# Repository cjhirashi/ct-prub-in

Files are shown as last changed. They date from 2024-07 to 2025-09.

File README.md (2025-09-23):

# 🏢 Sistema de Automatización HVAC - INNES Aire






> **Sistema integral de automatización** para acondicionamiento de aire, plantas de agua y laboratorio de pruebas especializadas, implementado en las instalaciones de **INNES Aire**.

---

## 🎯 **Visión General del Sistema**

### **Capacidades Principales**
- 🌡️ **Control de Clima**: Gestión automática de temperatura y calidad del aire
- ⚡ **Eficiencia Energética**: Optimización de consumo mediante algoritmos PI avanzados  
- 🔬 **Laboratorio Especializado**: Cuarto de pruebas para componentes HVAC
- 📊 **Monitoreo Integral**: Supervisión en tiempo real vía HMI centralizado

### **Infraestructura Técnica**
- **Red de Comunicación**: BACnet MS/TP e IP
- **Controladores**: 8 DDC KMC distribuidos estratégicamente
- **Protocolo Principal**: BACnet para interoperabilidad total
- **HMI**: Loytec LVIS para supervisión centralizada

---

## 🏗️ **Arquitectura del Sistema**

```
    🖥️ HMI Centralizado (LVIS)
         │
         │ BACnet/IP
         │
    🔄 Router BACnet (MS/TP ↔ IP)
         │
    ┌────┴────┬────────┬────────┬────────┐
    │         │        │        │        │
  UMA-01   UMA-02   Plantas   Vigas   Cuarto
    │         │        │        │      Pruebas
  6 DDC     5 DDC     11 DDC    4 DDC   21,22 DDC
```

---

## 🏭 **Subsistemas Principales**

<table>
<tr>
<td width="50%">

### **🌬️ Unidades Manejadoras**
- **[UMA-01](./UMA-01/README.md)** - Acondicionamiento principal
- **[UMA-02](./Plantas-de-Agua/UMA-02/README.md)** - Distribución secundaria

### **💧 Plantas de Agua**
- **[PAH](./Plantas-de-Agua/PAH/README.md)** - Agua Helada (7-12°C)
- **[PAF](./Plantas-de-Agua/PAF/README.md)** - Agua Fría (16-20°C)  
- **[PAC](./Plantas-de-Agua/PAC/README.md)** - Agua Caliente (40-50°C)

</td>
<td width="50%">

### **❄️ Control Zonal**
- **[Vigas Frías](./Vigas-Frias/README.md)** - 4 zonas independientes
- **Válvulas Belimo** - Control preciso de flujo

### **🧪 Laboratorio**
- **[Cuarto de Pruebas](./Cuarto-de-Pruebas/README.md)** - 15 VAVs + 7 Plenums
- **Calibración** - Sistemas de medición avanzados
- **I+D** - Desarrollo de componentes HVAC

</td>
</tr>
</table>

---

## 🖧 **Red de Controladores**

### **BACnet MS/TP Network**

| **Sistema** | **Controlador** | **Modelo** | **DI** | **MAC** | **Estado** |
|---|---|---|---|---|---|
| UMA-01 | Principal | KMC BAC-5901C | `10003` | `6` | 🟢 Operativo |
| Plantas de Agua | PAH-PAF-PAC-UMA02 | KMC BAC-5901C | `10002` | `5` | 🟢 Operativo |
| Vigas Frías | Control Zonal | KMC BAC-5901C | `10001` | `4` | 🟢 Operativo |
| Cuarto Pruebas | Controlador 1 | KMC BAC-5901C | `10021` | `21` | 🟢 Operativo |
| Cuarto Pruebas | Controlador 2 | KMC BAC-5901C | `10022` | `22` | 🟢 Operativo |

### **Dispositivos Especializados**

| **Dispositivo** | **Función** | **Protocolo** | **DI** | **MAC** |
|---|---|---|---|---|
| Chiller Agua Helada | ClimaFlex FLG | Modbus-BACnet | `12` | `12` |
| Chiller Agua Fría | ClimaFlex FLG | Modbus-BACnet | `11` | `11` |
| EV-AC | Belimo Válvula | BACnet MS/TP | `10008` | `8` |
| EV-AF | Belimo Válvula | BACnet MS/TP | `10009` | `9` |

### **Sensores Independientes**
- **SPT1-4_CP**: 4x Sensores Veris temperatura (MAC 23-26)

### **HMI & Supervisión**

| **Equipo** | **Protocolo** | **IP** | **Puerto** | **Función** |
|---|---|---|---|---|
| LVIS Display | BACnet/IP | `10.0.0.251` | `47808` | Supervisión Central |

---

## 📂 **Navegación del Repositorio**

```
📂 Sistema-Aire-INNES/
├── 📁 UMA-01/                    # Unidad Manejadora Principal
├── 📁 Plantas-de-Agua/           # PAH, PAF, PAC, UMA-02  
├── 📁 Vigas-Frias/               # Control Zonal (4 zonas)
├── 📁 Cuarto-de-Pruebas/         # Laboratorio (15 VAVs + 7 Plenums)
├── 📁 Documentación/             # Diagramas, Manuales, Guías
├── 📁 Recursos/                  # Imágenes, Videos, Referencias
└── 📄 README.md                  # Este archivo
```

### **🔗 Enlaces Rápidos**
- **[🚀 Guía de Inicio Rápido](./Documentación/Guías/inicio-rapido.md)**
- **[🔧 Manual de Mantenimiento](./Documentación/Manuales/mantenimiento.md)**
- **[⚡ Procedimientos de Emergencia](./Documentación/Guías/emergencias.md)**
- **[📊 Dashboard de Monitoreo](http://10.0.0.251:47808)** *(HMI LVIS)*

---

## 🎛️ **Puntos de Control Críticos**

### **Parámetros Operacionales**
| **Sistema** | **Setpoint** | **Rango Operación** | **Alarma** |
|---|---|---|---|
| PAH | 7°C | 5-12°C | <3°C / >15°C |
| PAF | 18°C | 16-22°C | <14°C / >25°C |
| PAC | 45°C | 40-55°C | <35°C / >60°C |
| Vigas Frías | 22°C | 20-26°C | <18°C / >28°C |

### **Estados del Sistema**
- 🟢 **Automático**: Control PI activo, sin intervención manual
- 🟡 **Manual**: Operación con setpoints fijos 
- 🔴 **Alarma**: Requiere intervención inmediata
- ⭕ **Mantenimiento**: Sistema fuera de servicio programado

---

## ⚠️ **Seguridad y Precauciones**

### **🚨 ANTES de cualquier intervención**
1. **Verificar estado del sistema** en HMI LVIS
2. **Desenergizar circuitos** en tablero correspondiente
3. **Colocar tarjeta LOTO** (Lock Out Tag Out)
4. **Verificar ausencia de tensión** con multímetro

### **🔧 Contactos de Emergencia**
- **Supervisor Técnico**: Ext. 101
- **Mantenimiento 24/7**: Ext. 911
- **Emergencias Eléctricas**: 📞 +52-XXX-XXX-XXXX

---

## 📈 **Estadísticas del Sistema**

<div align="center">






</div>

---

## 🔄 **Última Actualización**

- **Fecha**: Septiembre 2025
- **Versión**: 2.0
- **Cambios**: Reestructuración completa de documentación
- **Responsable**: Equipo Técnico INNES

---

<div align="center">

**💡 Para soporte técnico o sugerencias, contacta al equipo de automatización**





</div>

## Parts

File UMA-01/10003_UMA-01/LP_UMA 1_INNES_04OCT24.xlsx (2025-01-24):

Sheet: LISTA PUNTOS
 |  |  |  |  |  |  | LISTA DE PUNTOS DE CONTROL
cliente | INNES |  |  |  |  | controlador | BAC-5901C |  | sistema
proyecto | Cuarto de Pruebas |  |  |  |  | marca | KMC |  | Control de UMA-1
LISTA DE PUNTOS
 |  |  |  |  |  |  |  | RANGO |  |  |  | ESTADOS
ITEM | VARIABLE | TIPO | ID | NOMBRE | DESCRIPCIÓN | ESCRITURA | SEÑAL | MÍN | MÁX | UNIDADES | DEFAULT | ON | OFF | NOTAS
1 | INPUT | DIGITAL | 3 | ST_RA1 | ESTADO, RETORNO DE AIRE (OFICINAS) |  | ON/OFF
2 | INPUT | DIGITAL | 4 | ST_RA2 | ESTADO, RETORNO DE AIRE (CUARTO PRUEBAS) |  | ON/OFF
3 | INPUT | ANALOG | 5 | SAH1 | HUMEDAD, SUMINISTRO DE AIRE
4 | INPUT | ANALOG | 6 | SAT | TEMPERATURA, SUMINISTRO DE AIRE
5 | INPUT | ANALOG | 7 | MAH | HUMEDAD, MEZCLA DE AIRE
6 | INPUT | ANALOG | 8 | MAT | TEMPERATURA, MEZCLA DE AIRE
7 | INPUT | ANALOG | 9 | RAH | HUMEDAD, RETORNO DE AIRE
8 | INPUT | ANALOG | 10 | RAT | TEMPERATURA, RETORNO DE AIRE
9 | INPUT | ANALOG | 11 | OAT | TEMPERATURA, AIRE EXTERIOR
10 | INPUT | ANALOG | 12 | OAH | HUMEDAD, AIRE EXTERIOR
11 | INPUT | ANALOG | 13 | SAH | HUMEDAD, SUMINISTRO DE AIRE
12 | INPUT | ANALOG | 14 | DP | PRESION, SUMINISTRO DE AIRE
13 | INPUT | ANALOG | 15 | SAF | FLUJO, SUMINISTRO DE AIRE
14 | INPUT | ANALOG | 16 | RAF | FLUJO, RETORNO DE AIRE
15 | INPUT | ANALOG | 17 | EAF-DP | FLUJO, EXTRACCION DE AIRE
16 | INPUT | ANALOG | 18 | OAF | FLUJO, DE AIRE EXTERIOR
17 | INPUT | ANALOG | 19 | ST_CCV | ESTADO, VALVULA DE AGUA HELADA
18 | INPUT | ANALOG | 20 | ST_HCV | ESTADO, VALVULA DE AGUA CALIENTE
19 | INPUT | ANALOG | 21 | ST_MA | ESTADO, COMPUERTA DE MEZCLA DE AIRE
20 | INPUT | ANALOG | 22 | ST_RA | ESTADO, COMPUERTA DE RETORNO DE AIRE
21 | INPUT | ANALOG | 23 | ST_OA | ESTADO, COMPUERTA DE AIRE EXTERIOR
22 | INPUT | DIGITAL | 24 | ST_SA1 | ESTADO, SUMINISTRO DE AIRE (OFICINAS)
23 | INPUT | DIGITAL | 25 | ST_SA2 | ESTADO, SUMINISTRO DE AIRE (CUARTO PRUEBAS)
24 | INPUT | DIGITAL | 26 | ST_EF-OK | ESTADO, VENTILADOR DE EXTRACCION DE AIRE
25 | OUTPUT | DIGITAL | 1 | SS_SF | ARRANQUE: VENTILADOR DE SUMINISTRO DE AIRE
26 | OUTPUT | ANALOG | 2 | CN_SF | VELOCIDAD: VENTILADOR DE SUMINISTRO DE AIRE
27 | OUTPUT | DIGITAL | 3 | SS_EF | ARRANQUE: VENTILADOR DE EXTRACCION DE AIRE
28 | OUTPUT | ANALOG | 4 | CN_EF | VELOCIDAD: VENTILADOR DE EXTRACCION DE AIRE
29 | OUTPUT | ANALOG | 5 | CN_CCV | CONTROL: VALVULA DE AGUA HELADA
30 | OUTPUT | ANALOG | 6 | CN_HVC | CONTROL: VALVULA DE AGUA CALIENTE
31 | OUTPUT | ANALOG | 7 | CN_MA | CONTROL: COMPUERTA DE MEZCLA DE AIRE
32 | OUTPUT | ANALOG | 8 | CN_RA | CONTROL: COMPUERTA DE RETORNO DE AIRE
33 | OUTPUT | ANALOG | 9 | CN_OA | CONTROL: COMPUERTA DE AIRE EXTERIOR
34 | OUTPUT | DIGITAL | 10 | CN_SA1 | CONTROL: COMPUERTA DE SUMINISTRO DE AIRE (OFICINAS)
35 | OUTPUT | DIGITAL | 11 | CN_SA2 | CONTROL: COMPUERTA DE SUMINISTRO DE AIRE (CUARTO PRUEBAS)
36 | OUTPUT | DIGITAL | 12 | CN_RA1 | CONTROL: COMPUERTA DE RETORNO DE AIRE (OFICINAS)
37 | OUTPUT | DIGITAL | 13 | CN_RA2 | CONTROL: COMPUERTA DE RETORNO DE AIRE (CUARTO PRUEBAS)
 | VARIABLE | ANALOG | 1 | SP_SAT | SETPOINT: TEMPERATURA DE SUMINISTRO DE AIRE
 | VARIABLE | ANALOG | 2 | SP_SAH | SETPOINT: HUMEDAD DE SUMINISTRO DE AIRE
 | VARIABLE | ANALOG | 3 | SP_SPH | SETPOINT: HUMEDAD DE AREA
 | VARIABLE | ANALOG | 4 | SP_SPT_CP | SETPOINT: TEMPERATURA DE AREA (CUARTO PRUEBAS)
 | VARIABLE | ANALOG | 5 | SP_TEMP | SETPOINT: TEMPERATURA EN EFECTO
 | VARIABLE | ANALOG | 7 | SP_Q_SA | SETPOINT: CAUDAL DE AIRE SUMINISTRO (OFICINAS)
 | VARIABLE | ANALOG | 8 | SP_P_SA | SETPOINT: PRESION AIRE DE SUMINISTRO DE AREA (CUARTO PRUEBAS)
 | VARIABLE | ANALOG | 14 | Q_SA | CAUDAL, SUMINISTRO DE AIRE
 | VARIABLE | ANALOG | 15 | D_H_SA | ALTO DUCTO, SUMINISTRO DE AIRE
 | VARIABLE | ANALOG | 16 | D_W_SA | ANCHO DUCTO, SUMINISTRO DE AIRE
 | VARIABLE | ANALOG | 17 | Q_RA | CAUDAL, RETORNO DE AIRE
 | VARIABLE | ANALOG | 18 | D_H_RA | ALTO DUCTO, RETORNO DE AIRE
 | VARIABLE | ANALOG | 19 | D_W_RA | ANCHO DUCTO, RETORNO DE AIRE
 | VARIABLE | ANALOG | 20 | Q_EA | CAUDAL, EXTRACCION DE AIRE
 | VARIABLE | ANALOG | 21 | D_H_EA | ALTO DUCTO, EXTRACCION DE AIRE
 | VARIABLE | ANALOG | 22 | D_W_EA | ANCHO DUCTO, EXTRACCION DE AIRE
 | VARIABLE | ANALOG | 23 | Q_OA | CAUDAL, AIRE EXTERIOR
 | VARIABLE | ANALOG | 24 | D_H_OA | ALTO DUCTO, AIRE EXTERIOR
 | VARIABLE | ANALOG | 25 | D_W_OA | ANCHO DUCTO, AIRE EXTERIOR
 | VARIABLE | ANALOG | 26 | M_CN_SF | MANUAL: VELOCIDAD, VENTILADOR DE SUMINISTRO
 | VARIABLE | ANALOG | 27 | M_CN_EF | MANUAL: VELOCIDAD, VENTILADOR DE EXTRACCION
 | VARIABLE | ANALOG | 28 | M_CN_CCV | MANUAL: APERTURA, VALVULA DE AGUA HELADA
 | VARIABLE | ANALOG | 29 | M_CN_HCV | MANUAL: APERTURA, VALVULA DE AGUA CALIENTE
 | VARIABLE | ANALOG | 30 | M_CN_RA | MANUAL: APERTURA, COMPUERTA DE RETORNO
 | VARIABLE | ANALOG | 31 | M_CN_EA | MANUAL: APERTURA, COMPUERTA DE EXTRACCION
 | VARIABLE | ANALOG | 32 | M_CN_OA | MANUAL: APERTURA, COMPUERTA AIRE EXTERIOR
 | VARIABLE | ANALOG | 40 | OP_COM_MIX | APERTURA: COMPUERTAS, CAJA DE MEZCLA (USUARIO)
 | VARIABLE | ANALOG | 41 | CN_EF_U | CONTROL: VELOCIDAD VENTILADOR DE EXTRACCION (USUARIO)
 | VARIABLE | ANALOG | 50 | CN_SF_Hz | CONTROL: VENTILADOR DE SUMINISTRO (Hz)
 | VARIABLE | ANALOG | 51 | CN_EF_Hz | CONTROL: VENTILADOR DE EXTRACCION (Hz)
 | VARIABLE | DIGITAL | 1 | HORARIO | ESTADO: HORARIO
 | VARIABLE | DIGITAL | 2 | SS_SISTEMA | ACTIVACION: CONTROL DE UMA
 | VARIABLE | DIGITAL | 3 | ST_SISTEMA | ESTADO: CONTROL DE UMA
 | VARIABLE | DIGITAL | 4 | AREA | AREA EN OPERACIÓN
 | VARIABLE | DIGITAL | 10 | SS_COMP | ACTIVACION: CONTROL DE COMPUERTAS AIRE
 | VARIABLE | DIGITAL | 11 | ST_COMP | ESTADO: CONTROL DE COMPUERTAS AIRE
 | VARIABLE | DIGITAL | 12 | SS_VENT | ACTIVACION: CONTROL DE VENTILADOR SUMINISTRO
 | VARIABLE | DIGITAL | 13 | ST_VENT | ESTADO: CONTROL DE VENTILADOR SUMINISTRO
 | VARIABLE | DIGITAL | 14 | SS_TEMP | ACTIVACION: CONTROL DE TEMPERATURA
 | VARIABLE | DIGITAL | 15 | ST_TEMP | ESTADO: CONTROL DE TEMPERATURA
 | VARIABLE | DIGITAL | 16 | SS_HUM | ACTIVACION: CONTROL DE HUMEDAD
 | VARIABLE | DIGITAL | 17 | ST_HUM | ESTADO: CONTROL DE HUMEDAD
 | VARIABLE | DIGITAL | 18 | SS_VF | ACTIVACION: CONTROL DE VIGAS FRIAS
 | VARIABLE | DIGITAL | 19 | ST_VF | ESTADO: CONTROL DE VIGAS FRIAS
 | VARIABLE | DIGITAL | 23 | SS_EF_U | ARRANQUE: VENTILADOR DE EXTRACCION (USUARIO)
 | VARIABLE | DIGITAL | 24 | ST_SF | ESTADO: VENTILADOR DE SUMINISTRO
 | VARIABLE | DIGITAL | 25 | ST_EF | ESTADO: VENTILADOR DE EXTRACCION
 | VARIABLE | DIGITAL | 27 | ALM_UMA | ALARMA: SISTEMA DE CONTROL UMA
 | VARIABLE | DIGITAL | 28 | ALM_SF | ALARMA: VENTILADOR DE SUMINISTRO DE AIRE
 | VARIABLE | DIGITAL | 29 | ALM_EF | ALARMA: VENTILADOR DE EXTRACCION DE AIRE
 | VARIABLE | MULTISTATE | 1 | MODO | (1) HORARIO (2) ARRANQUE (3) PARO (4) CUARTO PRUEBAS
 | VARIABLE | MULTISTATE | 2 | RESET | (1) VENT SUMINISTRO (2) VENT RETORNO (3) TODO (4) NORMAL

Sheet: RECURSOS
VARIABLE | TIPO | SEÑAL | UNIDADES | ESCRITURA
INPUT | ANALOG | ON/OFF | °C | LECTURA
OUTPUT | DIGITAL | 0-10 VDC | °F | ESCRITURA
VARIABLE | MULTISTATE | 2-10 VDC | °K | LECT/ESC
PARAMETRO |  | 0-5 VDC | %RH
ALARMA |  | 1-5 VDC | %
 |  | 0-20 mA | "WC
 |  | 4-20 mA | PSI
 |  | 10K TII | Pas
 |  | 10K TIII | hr
 |  | PT1000 | min
 |  |  | seg
 |  |  | CFM
 |  |  | FPM
 |  |  | dias

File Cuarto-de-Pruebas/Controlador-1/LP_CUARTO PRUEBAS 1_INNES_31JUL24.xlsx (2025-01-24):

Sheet: LISTA PUNTOS
 |  |  |  |  |  |  | LISTA DE PUNTOS DE CONTROL
cliente | INNES |  |  |  |  | controlador | BAC-5901C |  | sistema
proyecto | Cuarto de Pruebas 1 |  |  |  |  | marca | KMC |  | Control de VAVs
LISTA DE PUNTOS
 |  |  |  |  |  |  |  | RANGO |  |  |  | ESTADOS
ITEM | VARIABLE | TIPO | ID | NOMBRE | DESCRIPCIÓN | ESCRITURA | SEÑAL | MÍN | MÁX | UNIDADES | DEFAULT | ON | OFF | NOTAS
1 | INPUT | ANALOG | 3 | P1_VM_DP | PLENUM 1, VAV 01 - MEDIANA, PRES DIF |  | 0-10 VDC | 0 | 2 | "WC
2 | INPUT | ANALOG | 4 | P1_VG_DP | PLENUM 1, VAV 02 - GRANDE, PRES DIF |  | 0-10 VDC | 0 | 2 | "WC
3 | INPUT | ANALOG | 5 | P2_VM_DP | PLENUM 2, VAV 01 - MEDIANA, PRES DIF |  | 0-10 VDC | 0 | 2 | "WC
4 | INPUT | ANALOG | 6 | P2_VG_DP | PLENUM 2, VAV 02 - GRANDE, PRES DIF |  | 0-10 VDC | 0 | 2 | "WC
5 | INPUT | ANALOG | 7 | P4_VM_DP | PLENUM 4, VAV 01 - MEDIANA, PRES DIF |  | 0-10 VDC | 0 | 2 | "WC
6 | INPUT | ANALOG | 8 | P4_VG_DP | PLENUM 4, VAV 02 - GRANDE, PRES DIF |  | 0-10 VDC | 0 | 2 | "WC
7 | INPUT | ANALOG | 9 | P4_VC_DP | PLENUM 4, VAV 03 - CHICA, PRES DIF |  | 0-10 VDC | 0 | 2 | "WC
8 | INPUT | ANALOG | 10 | P5_VC_DP | PLENUM 5, VAV 01 - CHICA, PRES DIF |  | 0-10 VDC | 0 | 2 | "WC
9 | INPUT | ANALOG | 11 | P5_VG_DP | PLENUM 5, VAV 02 - GRANDE, PRES DIF |  | 0-10 VDC | 0 | 2 | "WC
10 | INPUT | ANALOG | 12 | P6_VG_DP | PLENUM 6, VAV 01 - GRANDE, PRES DIF |  | 0-10 VDC | 0 | 2 | "WC
11 | INPUT | ANALOG | 13 | P6_VM_DP | PLENUM 6, VAV 02 - MEDIANA, PRES DIF |  | 0-10 VDC | 0 | 2 | "WC
12 | INPUT | ANALOG | 14 | PR7_VC_DP | PLENUM R7, VAV 01 - CHICA, PRES DIF |  | 0-10 VDC | 0 | 2 | "WC
13 | INPUT | ANALOG | 15 | PR7_VG_DP | PLENUM R7, VAV 02 - GRANDE, PRES DIF |  | 0-10 VDC | 0 | 2 | "WC
14 | INPUT | ANALOG | 16 | P1_VC_DP | PLENUM 1, VAV 03 - CHICA, PRES DIF |  | 0-10 VDC | 0 | 2 | "WC
15 | INPUT | ANALOG | 17 | P3_VG_DP | PLENUM 3, VAV 01 - GRANDE, PRES DIF |  | 0-10 VDC | 0 | 2 | "WC
15 | INPUT | ANALOG | 18 | P1_DP-1 | PLENUM 1, CAIDA DE PRESION 1 |  | 0-10 VDC |  |  | "WC
15 | INPUT | ANALOG | 19 | SAT | TEMPERATURA DE SUMINISTRO DE AIRE
15 | INPUT | ANALOG | 20 | V1_T1 | VELOCIDAD DE AIRE 1, TIRO 1
15 | INPUT | ANALOG | 21 | V2_T1 | VELOCIDAD DE AIRE 2, TIRO 1
15 | INPUT | ANALOG | 22 | V3_T1 | VELOCIDAD DE AIRE 3, TIRO 1
15 | INPUT | ANALOG | 23 | V4_T1 | VELOCIDAD DE AIRE 4, TIRO 1
15 | INPUT | ANALOG | 24 | V5_T1 | VELOCIDAD DE AIRE 5, TIRO 1
15 | INPUT | ANALOG | 25 | V6_T1 | VELOCIDAD DE AIRE 6, TIRO 1
15 | INPUT | ANALOG | 26 | V7_T1 | VELOCIDAD DE AIRE 7, TIRO 1
1 | OUTPUT | ANALOG | 1 | P1_VM_A | PLENUM 1, VAV 01 - MEDIANA, COMPUERTA |  | 2-10 VDC | 0 | 100 | %
2 | OUTPUT | ANALOG | 2 | P1_VG_A | PLENUM 1, VAV 02 - GRANDE, COMPUERTA |  | 2-10 VDC | 0 | 100 | %
3 | OUTPUT | ANALOG | 3 | P2_VM_A | PLENUM 2, VAV 01 - MEDIANA, COMPUERTA |  | 2-10 VDC | 0 | 100 | %
4 | OUTPUT | ANALOG | 4 | P2_VG_A | PLENUM 2, VAV 02 - GRANDE, COMPUERTA |  | 2-10 VDC | 0 | 100 | %
5 | OUTPUT | ANALOG | 5 | P4_VM_A | PLENUM 4, VAV 01 - MEDIANA, COMPUERTA |  | 2-10 VDC | 0 | 100 | %
6 | OUTPUT | ANALOG | 6 | P4_VG_A | PLENUM 4, VAV 02 - GRANDE, COMPUERTA |  | 2-10 VDC | 0 | 100 | %
7 | OUTPUT | ANALOG | 7 | P4_VC_A | VELOCIDAD DE AIRE 7, TIRO 2 |  | 2-10 VDC | 0 | 100 | %
8 | OUTPUT | ANALOG | 8 | P5_VC_A | PLENUM 5, VAV 01 - CHICA, COMPUERTA |  | 2-10 VDC | 0 | 100 | %
9 | OUTPUT | ANALOG | 9 | P5_VG_A | PLENUM 5, VAV 02 - GRANDE, COMPUERTA |  | 2-10 VDC | 0 | 100 | %
10 | OUTPUT | ANALOG | 10 | P6_VG_A | PLENUM 6, VAV 01 - GRANDE, COMPUERTA |  | 2-10 VDC | 0 | 100 | %
11 | OUTPUT | ANALOG | 11 | P6_VM_A | PLENUM 6, VAV 02 - MEDIANA, COMPUERTA |  | 2-10 VDC | 0 | 100 | %
12 | OUTPUT | ANALOG | 12 | PR7_VC_A | PLENUM R7, VAV 01 - CHICA, COMPUERTA |  | 2-10 VDC | 0 | 100 | %
13 | OUTPUT | ANALOG | 13 | PR7_VG_A | PLENUM R7, VAV 01 - GRANDE, COMPUERTA |  | 2-10 VDC | 0 | 100 | %
14 | OUTPUT | DIGITAL | 14 | P1_VM_AB | PLENUM 1, VAV 01 - MEDIANA, COMP BLOQ |  | ON/OFF |  |  |  |  | ABIERTA | CERRADA
15 | OUTPUT | DIGITAL | 15 | P1_VG_AB | PLENUM 1, VAV 02 - GRANDE, COMP BLOQ |  | ON/OFF |  |  |  |  | ABIERTA | CERRADA
16 | OUTPUT | DIGITAL | 16 | P2_VM_AB | PLENUM 2, VAV 01 - MEDIANA, COMP BLOQ |  | ON/OFF |  |  |  |  | ABIERTA | CERRADA
17 | OUTPUT | DIGITAL | 17 | PR7_VC_AB | PLENUM R7, VAV 01 - CHICA, COMP BLOQ |  | ON/OFF |  |  |  |  | ABIERTA | CERRADA
18 | OUTPUT | DIGITAL | 18 | PR7_VG_AB | PLENUM R7, VAV 02 - GRANDE, COMP BLOQ |  | ON/OFF |  |  |  |  | ABIERTA | CERRADA
19 | OUTPUT | DIGITAL | 19 | SS_HUMO | COMPUERTA DE MAQUINA DE HUMO |  | ON/OFF |  |  |  |  | ABIERTA | CERRADA
20 | OUTPUT | ANALOG | 21 | P1_VC_A | PLENUM 1, VAV 03 - CHICA, COMPUERTA |  | ON/OFF |  |  |  |  | ABIERTA | CERRADA
21 | OUTPUT | DIGITAL | 22 | P1_VC_AB | PLENUM 1, VAV 03 - CHICA, COMP BLOQ |  | ON/OFF |  |  |  |  | ABIERTA | CERRADA
22 | OUTPUT | ANALOG | 23 | P3_VG_A | PLENUM 3, VAV 01 - GRANDE, COMPUERTA |  | ON/OFF |  |  |  |  | ABIERTA | CERRADA
23 | OUTPUT | DIGITAL | 24 | P3_VG_AB | PLENUM 3, VAV 01 - GRANDE, COMP BLOQ |  | ON/OFF |  |  |  |  | ABIERTA | CERRADA
1 | VARIABLE | ANALOG | 1 | P1_VM_Q | PLENUM 1, VAV 01 - MEDIANA, CAUDAL |  |  |  |  | CFM | 0
2 | VARIABLE | ANALOG | 2 | P1_VM_M | PLENUM 1, VAV 01 - MEDIANA, MULTI |  |  |  |  |  | 1
3 | VARIABLE | ANALOG | 3 | P1_VM_O | PLENUM 1, VAV 01 - MEDIANA, OFFSET |  |  |  |  |  | 0
4 | VARIABLE | ANALOG | 4 | P1_VM_QF | PLENUM 1, VAV MEDIANA, CAUDAL FACTOR |  |  |  |  | CFM | 0
5 | VARIABLE | ANALOG | 5 | P1_VG_Q | PLENUM 1, VAV 02 - GRANDE, CAUDAL |  |  |  |  | CFM | 0
6 | VARIABLE | ANALOG | 6 | P1_VG_M | PLENUM 1, VAV 02 - GRANDE, MULTI |  |  |  |  |  | 1
7 | VARIABLE | ANALOG | 7 | P1_VG_O | PLENUM 1, VAV 02 - GRANDE, OFFSET |  |  |  |  |  | 0
8 | VARIABLE | ANALOG | 8 | P1_VG_QF | PLENUM 1, VAV GRANDE, CAUDAL FACTOR |  |  |  |  | CFM | 0
9 | VARIABLE | ANALOG | 9 | P1_Q | PLENUM 1, CAUDAL TOTAL |  |  |  |  | CFM | 0
10 | VARIABLE | ANALOG | 10 | P2_VM_Q | PLENUM 2, VAV 01 - MEDIANA, CAUDAL |  |  |  |  | CFM | 0
11 | VARIABLE | ANALOG | 11 | P2_VM_M | PLENUM 2, VAV 01 - MEDIANA, MULTI |  |  |  |  |  | 1
12 | VARIABLE | ANALOG | 12 | P2_VM_O | PLENUM 2, VAV 01 - MEDIANA, OFFSET |  |  |  |  |  | 0
13 | VARIABLE | ANALOG | 13 | P2_VM_QF | PLENUM 2, VAV MEDIANA, CAUDAL FACTOR |  |  |  |  | CFM | 0
14 | VARIABLE | ANALOG | 14 | P2_VG_Q | PLENUM 2, VAV 02 - GRANDE, CAUDAL |  |  |  |  | CFM | 0
15 | VARIABLE | ANALOG | 15 | P2_VG_M | PLENUM 2, VAV 02 - GRANDE, MULTI |  |  |  |  |  | 1
16 | VARIABLE | ANALOG | 16 | P2_VG_O | PLENUM 2, VAV 02 - GRANDE, OFFSET |  |  |  |  |  | 0
17 | VARIABLE | ANALOG | 17 | P2_VG_QF | PLENUM 2, VAV GRANDE, CAUDAL FACTOR |  |  |  |  | CFM | 0
18 | VARIABLE | ANALOG | 18 | P2_Q | PLENUM 2, CAUDAL TOTAL |  |  |  |  | CFM | 0
19 | VARIABLE | ANALOG | 19 | P4_VM_Q | PLENUM 4, VAV 01 - MEDIANA, CAUDAL |  |  |  |  | CFM | 0
20 | VARIABLE | ANALOG | 20 | P4_VM_M | PLENUM 4, VAV 01 - MEDIANA, MULTI |  |  |  |  |  | 1
21 | VARIABLE | ANALOG | 21 | P4_VM_O | PLENUM 4, VAV 01 - MEDIANA, OFFSET |  |  |  |  |  | 0
22 | VARIABLE | ANALOG | 22 | P4_VM_QF | PLENUM 4, VAV MEDIANA, CAUDAL FACTOR |  |  |  |  | CFM | 0
23 | VARIABLE | ANALOG | 23 | P4_VG_Q | PLENUM 4, VAV 02 - GRANDE, CAUDAL |  |  |  |  | CFM | 0
24 | VARIABLE | ANALOG | 24 | P4_VG_M | PLENUM 4, VAV 02 - GRANDE, MULTI |  |  |  |  |  | 1
25 | VARIABLE | ANALOG | 25 | P4_VG_O | PLENUM 4, VAV 02 - GRANDE, OFFSET |  |  |  |  |  | 0
26 | VARIABLE | ANALOG | 26 | P4_VG_QF | PLENUM 4, VAV GRANDE, CAUDAL FACTOR |  |  |  |  | CFM | 0
27 | VARIABLE | ANALOG | 27 | P4_VC_Q | PLENUM 4, VAV 03 - CHICA, CAUDAL |  |  |  |  | CFM | 0
28 | VARIABLE | ANALOG | 28 | P4_VC_M | PLENUM 4, VAV 03 - CHICA, MULTI |  |  |  |  |  | 1
29 | VARIABLE | ANALOG | 29 | P4_VC_O | PLENUM 4, VAV 03 - CHICA, OFFSET |  |  |  |  |  | 0
30 | VARIABLE | ANALOG | 30 | P4_VC_QF | PLENUM 4, VAV CHICA, CAUDAL FACTOR |  |  |  |  | CFM | 0
31 | VARIABLE | ANALOG | 31 | P4_Q | PLENUM 4, CAUDAL TOTAL |  |  |  |  | CFM | 0
32 | VARIABLE | ANALOG | 32 | P5_VC_Q | PLENUM 5, VAV 01 - CHICA, CAUDAL |  |  |  |  | CFM | 0
33 | VARIABLE | ANALOG | 33 | P5_VC_M | PLENUM 5, VAV 01 - CHICA, MULTI |  |  |  |  |  | 1
34 | VARIABLE | ANALOG | 34 | P5_VC_O | PLENUM 5, VAV 01 - CHICA, OFFSET |  |  |  |  |  | 0
35 | VARIABLE | ANALOG | 35 | P5_VC_QF | PLENUM 5, VAV CHICA, CAUDAL FACTOR |  |  |  |  | CFM | 0
36 | VARIABLE | ANALOG | 36 | P5_VG_Q | PLENUM 5, VAV 02 - GRANDE, CAUDAL |  |  |  |  | CFM | 0
37 | VARIABLE | ANALOG | 37 | P5_VG_M | PLENUM 5, VAV 02 - GRANDE, MULTI |  |  |  |  |  | 1
38 | VARIABLE | ANALOG | 38 | P5_VG_O | PLENUM 5, VAV 02 - GRANDE, OFFSET |  |  |  |  |  | 0
39 | VARIABLE | ANALOG | 39 | P5_VG_QF | PLENUM 5, VAV GRANDE, CAUDAL FACTOR |  |  |  |  | CFM | 0
40 | VARIABLE | ANALOG | 40 | P5_Q | PLENUM 5, CAUDAL TOTAL |  |  |  |  | CFM | 0
41 | VARIABLE | ANALOG | 41 | P6_VG_Q | PLENUM 6, VAV 01 - GRANDE, CAUDAL |  |  |  |  | CFM | 0
42 | VARIABLE | ANALOG | 42 | P6_VG_M | PLENUM 6, VAV 01 - GRANDE, MULTI |  |  |  |  |  | 1
43 | VARIABLE | ANALOG | 43 | P6_VG_O | PLENUM 6, VAV 01 - GRANDE, OFFSET |  |  |  |  |  | 0
44 | VARIABLE | ANALOG | 44 | P6_VG_QF | PLENUM 6, VAV GRANDE, CAUDAL FACTOR |  |  |  |  | CFM | 0
45 | VARIABLE | ANALOG | 45 | P6_VM_Q | PLENUM 6, VAV 02 - MEDIANA, CAUDAL |  |  |  |  | CFM | 0
46 | VARIABLE | ANALOG | 46 | P6_VM_M | PLENUM 6, VAV 02 - MEDIANA, MULTI |  |  |  |  |  | 1
47 | VARIABLE | ANALOG | 47 | P6_VM_O | PLENUM 6, VAV 02 - MEDIANA, OFFSET |  |  |  |  |  | 0
48 | VARIABLE | ANALOG | 48 | P6_VM_QF | PLENUM 6, VAV MEDIANA, CAUDAL FACTOR |  |  |  |  | CFM | 0
49 | VARIABLE | ANALOG | 49 | P6_Q | PLENUM 6, CAUDAL TOTAL |  |  |  |  | CFM | 0
50 | VARIABLE | ANALOG | 50 | PR7_VC_Q | PLENUM R7, VAV 01 - CHICA, CAUDAL |  |  |  |  | CFM | 0
51 | VARIABLE | ANALOG | 51 | PR7_VC_M | PLENUM R7, VAV 01 - CHICA, MULTI |  |  |  |  |  | 1
52 | VARIABLE | ANALOG | 52 | PR7_VC_O | PLENUM R7, VAV 01 - CHICA, OFFSET |  |  |  |  |  | 0
53 | VARIABLE | ANALOG | 53 | PR7_VC_QF | PLENUM R7, VAV CHICA, CAUDAL FACTOR |  |  |  |  | CFM | 0
54 | VARIABLE | ANALOG | 54 | PR7_VG_Q | PLENUM R7, VAV 02 - GRANDE, CAUDAL |  |  |  |  | CFM | 0
55 | VARIABLE | ANALOG | 55 | PR7_VG_M | PLENUM R7, VAV 02 - GRANDE, MULTI |  |  |  |  |  | 1
56 | VARIABLE | ANALOG | 56 | PR7_VG_O | PLENUM R7, VAV 02 - GRANDE, OFFSET |  |  |  |  |  | 0
57 | VARIABLE | ANALOG | 57 | PR7_VG_QF | PLENUM R7, VAV GRANDE, CAUDAL FACTOR |  |  |  |  | CFM | 0
58 | VARIABLE | ANALOG | 58 | PR7_Q | PLENUM R7, CAUDAL TOTAL |  |  |  |  | CFM | 0
59 | VARIABLE | ANALOG | 59 | P1_VC_Q | PLENUM 1, VAV 03 - CHICA, CAUDAL |  |  |  |  | CFM | 0
60 | VARIABLE | ANALOG | 60 | P1_VC_M | PLENUM 1, VAV 03 - CHICA, MULTI |  |  |  |  |  | 1
61 | VARIABLE | ANALOG | 61 | P1_VC_O | PLENUM 1, VAV 03 - CHICA, OFFSET |  |  |  |  |  | 0
62 | VARIABLE | ANALOG | 62 | P1_VC_QF | PLENUM 1, VAV 03 - CHICA, CAUDAL FACTOR |  |  |  |  | CFM | 0
63 | VARIABLE | ANALOG | 63 | P3_VG_Q | PLENUM 3, VAV 01 - CHICA, CAUDAL |  |  |  |  | CFM | 0
64 | VARIABLE | ANALOG | 64 | P3_VG_M | PLENUM 3, VAV 01 - CHICA, MULTI |  |  |  |  |  | 1
65 | VARIABLE | ANALOG | 65 | P3_VG_O | PLENUM 3, VAV 01 - CHICA, OFFSET |  |  |  |  |  | 0
66 | VARIABLE | ANALOG | 66 | P3_VG_QF | PLENUM 3, VAV 01 - CHICA, CAUDAL FACTOR |  |  |  |  | CFM | 0
67 | VARIABLE | ANALOG | 67 | P1_VC_DM | PLENUM 1, VAV 03 - CHICA, DEMANDA |  |  |  |  | %
68 | VARIABLE | ANALOG | 68 | P3_VG_DM | PLENUM 3, VAV 01 - GRANDE, DEMANDA |  |  |  |  | %
69 | VARIABLE | ANALOG | 69 | P_GR | DEMANDA, PROPORCIONAL CAJA GRANDE |  |  |  |  |  | 5
70 | VARIABLE | ANALOG | 70 | I_GR | DEMANDA, INTEGRAL CAJA GRANDE |  |  |  |  |  | 0.01
71 | VARIABLE | ANALOG | 71 | P_MD | DEMANDA, PROPORCIONAL CAJA MEDIANA |  |  |  |  |  | 5
72 | VARIABLE | ANALOG | 72 | I_MD | DEMANDA, INTEGRAL CAJA MEDIANA |  |  |  |  |  | 0.01
73 | VARIABLE | ANALOG | 73 | P_CH | DEMANDA, PROPORCIONAL CAJA CHICA |  |  |  |  |  | 5
74 | VARIABLE | ANALOG | 74 | I_CH | DEMANDA, INTEGRAL CAJA CHICA |  |  |  |  |  | 0.01
75 | VARIABLE | ANALOG | 75
76 | VARIABLE | ANALOG | 76
77 | VARIABLE | ANALOG | 77
78 | VARIABLE | ANALOG | 78
79 | VARIABLE | ANALOG | 80 | QR_VG_DM | DEMANDA, VAV GRANDE RETORNO |  |  |  |  | CFM
80 | VARIABLE | ANALOG | 81 | QR_VC_DM | DEMANDA, VAV CHICA RETORNO |  |  |  |  | CFM
81 | VARIABLE | ANALOG | 82 | Q_VG_DM | DEMANDA, VAV GRANDE |  |  |  |  | CFM
82 | VARIABLE | ANALOG | 83 | Q_VM_DM | DEMANDA, VAV MEDIANA |  |  |  |  | CFM
83 | VARIABLE | ANALOG | 84 | Q_VC_DM | DEMANDA, VAV CHICA |  |  |  |  | CFM
84 | VARIABLE | ANALOG | 85 | P1_VM_DM | PLENUM 1, VAV 01 - MEDIANA, DEMANDA |  |  |  |  | %
85 | VARIABLE | ANALOG | 86 | P1_VG_DM | PLENUM 1, VAV 02 - GRANDE, DEMANDA |  |  |  |  | %
86 | VARIABLE | ANALOG | 87 | P2_VM_DM | PLENUM 2, VAV 01 - MEDIANA, DEMANDA |  |  |  |  | %
87 | VARIABLE | ANALOG | 88 | P2_VG_DM | PLENUM 2, VAV 02 - GRANDE, DEMANDA |  |  |  |  | %
88 | VARIABLE | ANALOG | 89 | P4_VM_DM | PLENUM 4, VAV 01 - MEDIANA, DEMANDA |  |  |  |  | %
89 | VARIABLE | ANALOG | 90 | P4_VG_DM | PLENUM 4, VAV 02 - GRANDE, DEMANDA |  |  |  |  | %
90 | VARIABLE | ANALOG | 91 | P4_VC_DM | PLENUM 4, VAV 03 - CHICA, DEMANDA |  |  |  |  | %
91 | VARIABLE | ANALOG | 92 | P5_VC_DM | PLENUM 5, VAV 01 - CHICA, DEMANDA |  |  |  |  | %
92 | VARIABLE | ANALOG | 93 | P5_VG_DM | PLENUM 5, VAV 02 - GRANDE, DEMANDA |  |  |  |  | %
93 | VARIABLE | ANALOG | 94 | P6_VG_DM | PLENUM 6, VAV 01 - GRANDE, DEMANDA |  |  |  |  | %
94 | VARIABLE | ANALOG | 95 | P6_VM_DM | PLENUM 6, VAV 02 - MEDIANA, DEMANDA |  |  |  |  | %
95 | VARIABLE | ANALOG | 96 | PR7_VC_DM | PLENUM R7, VAV 01 - CHICA, DEMANDA |  |  |  |  | %
96 | VARIABLE | ANALOG | 97 | PR7_VG_DM | PLENUM R7, VAV 02 - GRANDE, DEMANDA |  |  |  |  | %
97 | VARIABLE | ANALOG | 98 | Q_VG | CAUDAL DE VAV GRANDE ACTIVA |  |  |  |  | CFM
98 | VARIABLE | ANALOG | 99 | Q_VM | CAUDAL DE VAV MEDIANA ACTIVA |  |  |  |  | CFM
99 | VARIABLE | ANALOG | 100 | Q_VC | CAUDAL DE VAV CHICA ACTIVA |  |  |  |  | CFM
100 | VARIABLE | ANALOG | 101 | Q_T | CAUDAL DE VAVS ACTIVAS |  |  |  |  | CFM
101 | VARIABLE | ANALOG | 102 | QR_VG | CAUDAL DE VAV GRANDE RETORNO |  |  |  |  | CFM
102 | VARIABLE | ANALOG | 103 | QR_VC | CAUDAL DE VAV CHICA RETORNO |  |  |  |  | CFM
103 | VARIABLE | ANALOG | 104 | QR_T | CAUDAL DE VAVS RETORNO |  |  |  |  | CFM
104 | VARIABLE | ANALOG | 105 | DP_1 | PRESION 1, PLENUM ACTIVO |  |  |  |  | "WC
105 | VARIABLE | ANALOG | 106 | DP_2 | PRESION 2, PLENUM ACTIVO |  |  |  |  | "WC
106 | VARIABLE | ANALOG | 107 | SP-Q_VG | SETPOINT DE CAUDAL, VAV GRANDE ACTIVA |  |  |  |  | CFM
107 | VARIABLE | ANALOG | 108 | SP-Q_VM | SETPOINT DE CAUDAL, VAV MEDIANA ACTIVA |  |  |  |  | CFM
108 | VARIABLE | ANALOG | 109 | SP-Q_VC | SETPOINT DE CAUDAL, VAV CHICA ACTIVA |  |  |  |  | CFM
109 | VARIABLE | ANALOG | 110 | SP_Q_VGR | SETPOINT DE CAUDAL, VAV GRANDE RETORNO |  |  |  |  | CFM
110 | VARIABLE | ANALOG | 111 | SP_Q_VCR | SETPOINT DE CAUDAL, VAV CHICA RETORNO |  |  |  |  | CFM
111 | VARIABLE | ANALOG | 112 | MIN_VG | CAUDAL MINIMO, VAV GRANDE ACTIVA |  |  |  |  | CFM
112 | VARIABLE | ANALOG | 113 | MAX_VG | CAUDAL MAXIMO, VAV GRANDE ACTIVA |  |  |  |  | CFM
113 | VARIABLE | ANALOG | 114 | MIN_VM | CAUDAL MINIMO, VAV MEDIANA ACTIVA |  |  |  |  | CFM
114 | VARIABLE | ANALOG | 115 | MAX_VM | CAUDAL MAXIMO, VAV MEDIANA ACTIVA |  |  |  |  | CFM
115 | VARIABLE | ANALOG | 116 | MIN_VC | CAUDAL MINIMO, VAV CHICA ACTIVA |  |  |  |  | CFM
116 | VARIABLE | ANALOG | 117 | MAX_VC | CAUDAL MAXIMO, VAV CHICA ACTIVA |  |  |  |  | CFM
117 | VARIABLE | ANALOG | 118 | SP_SAT | SETPOINT TEMPERATURA DE SUMINISTRO |  |  |  |  | °C | 20
118 | VARIABLE | ANALOG | 119 | SP_DP | SETPOINT PRESION DIFERENCIAL |  |  |  |  | "WC | 1
119 | VARIABLE | ANALOG | 120
120 | VARIABLE | DIGITAL | 1 | SS_CP | ACTIVACION SISTEMA DE CUARTO DE PRUEBAS |  |  |  |  |  |  | ACTIVO | INACTIVO
121 | VARIABLE | DIGITAL | 2 | ST_CP | ESTADO SISTEMA DE CUARTO DE PRUEBAS |  |  |  |  |  |  | ACTIVO | INACTIVO
122 | VARIABLE | DIGITAL | 3 | ST_P1 | ESTADO PLENUM 1 |  |  |  |  |  |  | ACTIVO | INACTIVO
123 | VARIABLE | DIGITAL | 4 | ST_P2 | ESTADO PLENUM 2 |  |  |  |  |  |  | ACTIVO | INACTIVO
124 | VARIABLE | DIGITAL | 5 | ST_P3 | ESTADO PLENUM 3 |  |  |  |  |  |  | ACTIVO | INACTIVO
125 | VARIABLE | DIGITAL | 6 | ST_P4 | ESTADO PLENUM 4 |  |  |  |  |  |  | ACTIVO | INACTIVO
126 | VARIABLE | DIGITAL | 7 | ST_P5 | ESTADO PLENUM 5 |  |  |  |  |  |  | ACTIVO | INACTIVO
127 | VARIABLE | DIGITAL | 8 | ST_P6 | ESTADO PLENUM 6 |  |  |  |  |  |  | ACTIVO | INACTIVO
128 | VARIABLE | DIGITAL | 9 | PERM_VG | PERMISO DE SISTEMA, VAV GRANDE |  |  |  |  |  |  | ACTIVO | INACTIVO
129 | VARIABLE | DIGITAL | 10 | PERM_VM | PERMISO DE SISTEMA, VAV MEDIANA |  |  |  |  |  |  | ACTIVO | INACTIVO
130 | VARIABLE | DIGITAL | 11 | PERM_VC | PERMISO DE SISTEMA, VAV CHICA |  |  |  |  |  |  | ACTIVO | INACTIVO
131 | VARIABLE | DIGITAL | 12 | ACTIV (calib) | ACTIVACION DE SISTEMA DE CALIBRACION |  |  |  |  |  |  | ACTIVO | INACTIVO
132 | VARIABLE | DIGITAL | 13 | INICIAR (calib) | INICIAR CALIBRACION |  |  |  |  |  |  | ACTIVO | INACTIVO
133 | VARIABLE | DIGITAL | 14 | COMP (calib) | SELECTOR DE PORCENTAJE DE APER DE COMP |  |  |  |  |  |  | HI | LW
134 | VARIABLE | DIGITAL | 15 | LEER (calib) | LEER FACTOR DE CORRECCION |  |  |  |  |  |  | ACTIVO | INACTIVO
135 | VARIABLE | DIGITAL | 16 | RESET (calib) | RESET FACTOR DE CORRECCION |  |  |  |  |  |  | ACTIVO | INACTIVO
136 | VARIABLE | DIGITAL | 17 | CALC (calib) | CALCULAR FACTOR DE CORRECCION |  |  |  |  |  |  | ACTIVO | INACTIVO
137 | VARIABLE | DIGITAL | 18 | CALIBRAR (calib) | ASIGNAR FACTOR DE CORRECCION |  |  |  |  |  |  | ACTIVO | INACTIVO
138 | VARIABLE | DIGITAL | 32 | PER_VAV_GR | PERMISIVO DE OPERACIÓN DE CAJA GRANDE |  |  |  |  |  |  | ACTIVO | INACTIVO
139 | VARIABLE | DIGITAL | 33 | PER_VAV_MD | PERMISIVO DE OPERACIÓN DE CAJA MEDIANA |  |  |  |  |  |  | ACTIVO | INACTIVO
140 | VARIABLE | DIGITAL | 34 | PER_VAV_CH | PERMISIVO DE OPERACIÓN DE CAJA CHICA |  |  |  |  |  |  | ACTIVO | INACTIVO
141 | VARIABLE | DIGITAL | 35 | PER_VAV_R-GR | PERMISIVO DE OPERACIÓN DE CAJA GRANDE |  |  |  |  |  |  | ACTIVO | INACTIVO
142 | VARIABLE | DIGITAL | 36 | PER_VAV_R-CH | PERMISIVO DE OPERACIÓN DE CAJA CHICA |  |  |  |  |  |  | ACTIVO | INACTIVO
143 | VARIABLE | DIGITAL | 38 | LOOP_PI | LAZO DE CONTROL EN OPERACIÓN |  |  |  |  |  |  | CJH | KMC
144 | VARIABLE | DIGITAL | 40 | B_VAV_GR | COMPUERTA DE BLOQUEO, VAV GRANDE |  |  |  |  |  |  | ON | OFF
145 | VARIABLE | DIGITAL | 41 | B_VAV_MD | COMPUERTA DE BLOQUEO, VAV MEDIANA |  |  |  |  |  |  | ON | OFF
146 | VARIABLE | DIGITAL | 42 | B_VAV_CH | COMPUERTA DE BLOQUEO, VAV CHICA |  |  |  |  |  |  | ON | OFF
147 | VARIABLE | MULTISTATE | 1 | PLENUM | PLENUM EN OPERACIÓN |  |  |  | (1)PLENUM 1 (2)PLENUM 2 (3)PLENUM 3 (4)PLENUM 4 (5)PLENUM 5 (6)PLENUM 6
148 | VARIABLE | MULTISTATE | 2 | EQ_CFM_VAV | CALIBRACION VAV |  |  |  | (1)PL1_VAV1 (2)PL1_VAV2 (3)PL2_VAV1 (4)PL2_VAV2 (5)PL3_VAV1 (6)PL3_VAV2 (7)PL3_VAV3 (8)PL4_VAV1 (9)PL4_VAV2 (10)PL5_VAV1 (11)PL5_VAV2 (12)PL6_VAV1 (13)PL6_VAV2
149 | VARIABLE | MULTISTATE | 3 | CAL_CFM_VAV | CALIBRACION VAV |  |  |  | (1)P1_VM (2)P1_VG (3)P1_VC (4)P2_VM (5)P2_VG (6)P3_VG (7)P4_VM (8)P4_VG (9)P4_VC (10)P5_VC (11)P5_VG (12)P6_VG (13)P6_VM (14)PR7_VC (15)PR7_VG (16)INACTIVO

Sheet: RECURSOS
VARIABLE | TIPO | SEÑAL | UNIDADES | ESCRITURA
INPUT | ANALOG | ON/OFF | °C | LECTURA
OUTPUT | DIGITAL | 0-10 VDC | °F | ESCRITURA
VARIABLE | MULTISTATE | 2-10 VDC | °K | LECT/ESC
PARAMETRO |  | 0-5 VDC | %RH
ALARMA |  | 1-5 VDC | %
 |  | 0-20 mA | "WC
 |  | 4-20 mA | PSI
 |  | 10K TII | Pas
 |  | 10K TIII | hr
 |  | PT1000 | min
 |  |  | seg
 |  |  | CFM
 |  |  | FPM
 |  |  | dias

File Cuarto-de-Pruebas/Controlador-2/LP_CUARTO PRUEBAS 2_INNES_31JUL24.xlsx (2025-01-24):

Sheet: LISTA PUNTOS
 |  |  |  |  |  | LISTA DE PUNTOS DE CONTROL
cliente | INNES |  |  |  |  | controlador | BAC-5901C |  | sistema
proyecto | Cuarto de Pruebas 2 |  |  |  |  | marca | KMC |  | Control de VAVs
LISTA DE PUNTOS
 |  |  |  |  |  |  |  | RANGO |  |  |  | ESTADOS
ITEM | VARIABLE | TIPO | ID | NOMBRE | DESCRIPCIÓN | ESCRITURA | SEÑAL | MÍN | MÁX | UNIDADES | DEFAULT | ON | OFF | NOTAS
1 | INPUT | ANALOG | 3 | P1_DP-2 | PLENUM 1, CAIDA DE PRESION 2 |  | 0-10 VDC | 0 | 2 | "WC
2 | INPUT | ANALOG | 4 | P2_DP | PLENUM 2, CAIDA DE PRESION |  |  |  |  | "WC
3 | INPUT | ANALOG | 5 | P4_DP | PLENUM 4, CAIDA DE PRESION |  |  |  |  | "WC
4 | INPUT | ANALOG | 6 | P5_DP | PLENUM 5, CAIDA DE PRESION |  |  |  |  | "WC
5 | INPUT | ANALOG | 7 | P6_DP | PLENUM 6, CAIDA DE PRESION |  |  |  |  | "WC
6 | INPUT | ANALOG | 8 | PR7_DP | PLENUM R7, CAIDA DE PRESION |  |  |  |  | "WC
7 | INPUT | ANALOG | 10 | V8 | VELOCIDAD 8
9 | INPUT | ANALOG | 11 | V1_T2 | VELOCIDAD DE AIRE 1, TIRO 2
10 | INPUT | ANALOG | 12 | V2_T2 | VELOCIDAD DE AIRE 2, TIRO 2
11 | INPUT | ANALOG | 13 | V3_T2 | VELOCIDAD DE AIRE 3, TIRO 2
12 | INPUT | ANALOG | 14 | V4_T2 | VELOCIDAD DE AIRE 4, TIRO 2
13 | INPUT | ANALOG | 15 | V5_T2 | VELOCIDAD DE AIRE 5, TIRO 2
14 | INPUT | ANALOG | 16 | V6_T2 | VELOCIDAD DE AIRE 6, TIRO 2
15 | INPUT | ANALOG | 17 | V7_T2 | VELOCIDAD DE AIRE 7, TIRO 2
16 | INPUT | ANALOG | 19 | V1_T3 | VELOCIDAD DE AIRE 1, TIRO 3
17 | INPUT | ANALOG | 20 | V2_T3 | VELOCIDAD DE AIRE 2, TIRO 3
18 | INPUT | ANALOG | 21 | V3_T3 | VELOCIDAD DE AIRE 3, TIRO 3
19 | INPUT | ANALOG | 22 | V4_T3 | VELOCIDAD DE AIRE 4, TIRO 3
20 | INPUT | ANALOG | 23 | V5_T3 | VELOCIDAD DE AIRE 5, TIRO 3
21 | INPUT | ANALOG | 24 | V6_T3 | VELOCIDAD DE AIRE 6, TIRO 3
22 | INPUT | ANALOG | 25 | V7_T3 | VELOCIDAD DE AIRE 7, TIRO 3
1 | OUTPUT | DIGITAL | 1 | P2_VG_AB | PLENUM 2, VAV 02 - GRANDE, COMP BLOQ |  |  |  |  |  |  | ABIERTA | CERRADA
2 | OUTPUT | DIGITAL | 2 | P4_VM_AB | PLENUM 4, VAV 01 - MEDIANA, COMP BLOQ |  |  |  |  |  |  | ABIERTA | CERRADA
3 | OUTPUT | DIGITAL | 3 | P4_VG_AB | PLENUM 4, VAV 02 - GRANDE, COMP BLOQ |  |  |  |  |  |  | ABIERTA | CERRADA
4 | OUTPUT | DIGITAL | 4 | P4_VC_AB | PLENUM 4, VAV 03 - CHICA, COMP BLOQ |  |  |  |  |  |  | ABIERTA | CERRADA
5 | OUTPUT | DIGITAL | 5 | P5_VC_AB | PLENUM 5, VAV 01 - CHICA, COMP BLOQ |  |  |  |  |  |  | ABIERTA | CERRADA
6 | OUTPUT | DIGITAL | 6 | P5_VG_AB | PLENUM 5, VAV 02 - GRANDE, COMP BLOQ |  |  |  |  |  |  | ABIERTA | CERRADA
7 | OUTPUT | DIGITAL | 7 | P6_VG_AB | PLENUM 6, VAV 01 - GRANDE, COMP BLOQ |  |  |  |  |  |  | ABIERTA | CERRADA
8 | OUTPUT | DIGITAL | 8 | P6_VM_AB | PLENUM 6, VAV 02 - MEDIANA, COMP BLOQ |  |  |  |  |  |  | ABIERTA | CERRADA
1 | VARIABLE | ANALOG | 1 | TEMP_PROM | TEMPERATURA PROMEDIO DE CUARTO
2 | VARIABLE | ANALOG | 2 | TEMP_1 | TEMPERATURA DE CUARTO 1
3 | VARIABLE | ANALOG | 3 | TEMP_2 | TEMPERATURA DE CUARTO 2
4 | VARIABLE | ANALOG | 4 | TEMP_3 | TEMPERATURA DE CUARTO 3
5 | VARIABLE | ANALOG | 5 | TEMP_4 | TEMPERATURA DE CUARTO 4
6 | VARIABLE | ANALOG | 6
7 | VARIABLE | ANALOG | 7 | CAL_MUES_ACT | NÚMERO DE MUESTRA ACTIVA
8 | VARIABLE | ANALOG | 8 | CAL_NUM_MUES | NÚMERO DE MUESTRAS
9 | VARIABLE | ANALOG | 9 | CAL_TM_MUES | TIEMPO ENTRE MUESTRAS
10 | VARIABLE | ANALOG | 10 | CAL_NUM_MAX | NÚMERO MÁXIMO DE MUESTRAS
11 | VARIABLE | ANALOG | 11 | CAL_NUM_MIN | NÚMERO MÍNIMO DE MUESTRAS
12 | VARIABLE | ANALOG | 12 | CAL_TM_MAX | TIEMPO MÁXIMO PARA TOMA DE MUESTRAS
13 | VARIABLE | ANALOG | 13 | CAL_TM_MIN | TIEMPO MÍNIMO PARA TOMA DE MUESTRAS
14 | VARIABLE | ANALOG | 14 | CAL_MULTI | MULTIPLICADOR SISTEMA DE CALIBRACIÓN
15 | VARIABLE | ANALOG | 15 | CAL_OFFSET | OFFSET SISTEMA DE CALIBRACION
16 | VARIABLE | ANALOG | 16 | CAL_HI_BAL | MEDICIÓN DE CAUDALES, RANGO ALTO, BALOMETRO
17 | VARIABLE | ANALOG | 17 | CAL_LW_BAL | MEDICIÓN DE CAUDALES, RANGO BAJO, BALOMETRO
18 | VARIABLE | ANALOG | 18 | CAL_HI_SIS | MEDICIÓN DE CAUDALES, RANGO ALTO, SISTEMA
19 | VARIABLE | ANALOG | 19 | CAL_LW_SIS | MEDICIÓN DE CAUDALES, RANGO BAJO, SISTEMA
20 | VARIABLE | ANALOG | 20 | CAL_PR_HI | PORCENTAJE DE APERTURA ALTO
21 | VARIABLE | ANALOG | 21 | CAL_PR_LW | PROCENTAJE DE APERTURA BAJO
22 | VARIABLE | ANALOG | 22
23 | VARIABLE | ANALOG | 23
24 | VARIABLE | ANALOG | 24
25 | VARIABLE | ANALOG | 25
26 | VARIABLE | ANALOG | 26 | NUM_MUESTRA | NUMEROS DE MUESTRAS
27 | VARIABLE | ANALOG | 27 | TM_MUESTRA | TIEMPO ENTRE MUESTRAS
28 | VARIABLE | ANALOG | 28
29 | VARIABLE | ANALOG | 31 | V_PROM_1 | VARIABLE PROMEDIO
30 | VARIABLE | ANALOG | 32 | V_MAX_1 | VARIABLE MAXIMA
31 | VARIABLE | ANALOG | 33 | V_MIN_1 | VARIABLE MINIMA
32 | VARIABLE | ANALOG | 34 | V_PROM_2 | VARIABLE PROMEDIO
33 | VARIABLE | ANALOG | 35 | V_MAX_2 | VARIABLE MAXIMA
34 | VARIABLE | ANALOG | 36 | V_MIN_2 | VARIABLE MINIMA
35 | VARIABLE | ANALOG | 37 | V_PROM_3 | VARIABLE PROMEDIO
36 | VARIABLE | ANALOG | 38 | V_MAX_3 | VARIABLE MAXIMA
37 | VARIABLE | ANALOG | 39 | V_MIN_3 | VARIABLE MINIMA
38 | VARIABLE | ANALOG | 40 | V_PROM_4 | VARIABLE PROMEDIO
39 | VARIABLE | ANALOG | 41 | V_MAX_4 | VARIABLE MAXIMA
40 | VARIABLE | ANALOG | 42 | V_MIN_4 | VARIABLE MINIMA
41 | VARIABLE | ANALOG | 43 | V_PROM_5 | VARIABLE PROMEDIO
42 | VARIABLE | ANALOG | 44 | V_MAX_5 | VARIABLE MAXIMA
43 | VARIABLE | ANALOG | 45 | V_MIN_5 | VARIABLE MINIMA
44 | VARIABLE | ANALOG | 46 | V_PROM_6 | VARIABLE PROMEDIO
45 | VARIABLE | ANALOG | 47 | V_MAX_6 | VARIABLE MAXIMA
46 | VARIABLE | ANALOG | 48 | V_MIN_6 | VARIABLE MINIMA
47 | VARIABLE | ANALOG | 49 | V_PROM_7 | VARIABLE PROMEDIO
48 | VARIABLE | ANALOG | 50 | V_MAX_7 | VARIABLE MAXIMA
49 | VARIABLE | ANALOG | 51 | V_MIN_7 | VARIABLE MINIMA
50 | VARIABLE | ANALOG | 52 | V_PROM_8 | VARIABLE PROMEDIO
51 | VARIABLE | ANALOG | 53 | V_MAX_8 | VARIABLE MAXIMA
52 | VARIABLE | ANALOG | 54 | V_MIN_8 | VARIABLE MINIMA
53 | VARIABLE | ANALOG | 55 | V_PROM_9 | VARIABLE PROMEDIO
54 | VARIABLE | ANALOG | 56 | V_MAX_9 | VARIABLE MAXIMA
55 | VARIABLE | ANALOG | 57 | V_MIN_9 | VARIABLE MINIMA
56 | VARIABLE | ANALOG | 58 | V_PROM_10 | VARIABLE PROMEDIO
57 | VARIABLE | ANALOG | 59 | V_MAX_10 | VARIABLE MAXIMA
58 | VARIABLE | ANALOG | 60 | V_MIN_10 | VARIABLE MINIMA
59 | VARIABLE | ANALOG | 61 | V_MAN_1 | VARIABLE MANUAL
60 | VARIABLE | ANALOG | 62 | V_MAN_2 | VARIABLE MANUAL
61 | VARIABLE | ANALOG | 63 | V_MAN_3 | VARIABLE MANUAL
62 | VARIABLE | ANALOG | 64 | V_MAN_4 | VARIABLE MANUAL
63 | VARIABLE | ANALOG | 65 | V_MAN_5 | VARIABLE MANUAL
64 | VARIABLE | ANALOG | 66 | V_MAN_6 | VARIABLE MANUAL
65 | VARIABLE | ANALOG | 67 | V_MAN_7 | VARIABLE MANUAL
66 | VARIABLE | ANALOG | 68 | V_MAN_8 | VARIABLE MANUAL
67 | VARIABLE | ANALOG | 69 | V_MAN_9 | VARIABLE MANUAL
68 | VARIABLE | ANALOG | 70 | V_MAN_10 | VARIABLE MANUAL
69 | VARIABLE | ANALOG | 71 | V_GRUPO-1_1 | VARIABLE
70 | VARIABLE | ANALOG | 72 | V_GRUPO-1_2 | VARIABLE
71 | VARIABLE | ANALOG | 73 | V_GRUPO-1_3 | VARIABLE
72 | VARIABLE | ANALOG | 74 | V_GRUPO-1_4 | VARIABLE
73 | VARIABLE | ANALOG | 75 | V_GRUPO-2_1 | VARIABLE
74 | VARIABLE | ANALOG | 76 | V_GRUPO-2_2 | VARIABLE
75 | VARIABLE | ANALOG | 77 | V_GRUPO-2_3 | VARIABLE
76 | VARIABLE | ANALOG | 78 | V_GRUPO-2_4 | VARIABLE
77 | VARIABLE | ANALOG | 79 | V_GRUPO-3_1 | VARIABLE
78 | VARIABLE | ANALOG | 80 | V_GRUPO-3_2 | VARIABLE
79 | VARIABLE | ANALOG | 81 | V_GRUPO-3_3 | VARIABLE
80 | VARIABLE | ANALOG | 82 | V_GRUPO-3_4 | VARIABLE
81 | VARIABLE | ANALOG | 83 | V_GRUPO-4_1 | VARIABLE
82 | VARIABLE | ANALOG | 84 | V_GRUPO-4_2 | VARIABLE
83 | VARIABLE | ANALOG | 85 | V_GRUPO-4_3 | VARIABLE
84 | VARIABLE | ANALOG | 86 | V_GRUPO-4_4 | VARIABLE
85 | VARIABLE | ANALOG | 87 | V_GRUPO-5_1 | VARIABLE
86 | VARIABLE | ANALOG | 88 | V_GRUPO-5_2 | VARIABLE
87 | VARIABLE | ANALOG | 89 | V_GRUPO-5_3 | VARIABLE
88 | VARIABLE | ANALOG | 90 | V_GRUPO-5_4 | VARIABLE
89 | VARIABLE | ANALOG | 91 | V_GRUPO-6_1 | VARIABLE
90 | VARIABLE | ANALOG | 92 | V_GRUPO-6_2 | VARIABLE
91 | VARIABLE | ANALOG | 93 | V_GRUPO-6_3 | VARIABLE
92 | VARIABLE | ANALOG | 94 | V_GRUPO-6_4 | VARIABLE
93 | VARIABLE | ANALOG | 95 | V_GRUPO-7_1 | VARIABLE
94 | VARIABLE | ANALOG | 96 | V_GRUPO-7_2 | VARIABLE
95 | VARIABLE | ANALOG | 97 | V_GRUPO-7_3 | VARIABLE
96 | VARIABLE | ANALOG | 98 | V_GRUPO-7_4 | VARIABLE
97 | VARIABLE | ANALOG | 99 | V_GRUPO-8_1 | VARIABLE
98 | VARIABLE | ANALOG | 100 | V_GRUPO-8_2 | VARIABLE
99 | VARIABLE | ANALOG | 101 | V_GRUPO-8_3 | VARIABLE
100 | VARIABLE | ANALOG | 102 | V_GRUPO-8_4 | VARIABLE
101 | VARIABLE | ANALOG | 103 | V_GRUPO-9_1 | VARIABLE
102 | VARIABLE | ANALOG | 104 | V_GRUPO-9_2 | VARIABLE
103 | VARIABLE | ANALOG | 105 | V_GRUPO-9_3 | VARIABLE
104 | VARIABLE | ANALOG | 106 | V_GRUPO-9_4 | VARIABLE
105 | VARIABLE | ANALOG | 107 | V_GRUPO-10_1 | VARIABLE
106 | VARIABLE | ANALOG | 108 | V_GRUPO-10_2 | VARIABLE
107 | VARIABLE | ANALOG | 109 | V_GRUPO-10_3 | VARIABLE
108 | VARIABLE | ANALOG | 110 | V_GRUPO-10_4 | VARIABLE
109 | VARIABLE | ANALOG | 120
110 | VARIABLE | ANALOG | 121
111 | VARIABLE | ANALOG | 122
112 | VARIABLE | ANALOG | 123
113 | VARIABLE | DIGITAL | 1 | CAL_ACTIV | ACTIVACIÓN DE SISTEMA DE CALIBRACIÓN
114 | VARIABLE | DIGITAL | 2 | CAL_INICIO | INICIO DE TOMA DE MUESTRAS PARA CALIBRACIÓN
115 | VARIABLE | DIGITAL | 3 | CAL_LEER | LEER FACTOR DE CALIBRACIÓN EXISTENTE
116 | VARIABLE | DIGITAL | 4 | CAL_RESET | RESET DE VARIABLES DE FACTOR CALIBRACIÓN
117 | VARIABLE | DIGITAL | 5 | CAL_CALCULO | CÁLCULO DE FACTOR DE CALIBRACIÓN
118 | VARIABLE | DIGITAL | 6 | CAL_CALIBRAR | CALIBRACIÓN DE MEDICIÓN DE CAUDALES
119 | VARIABLE | DIGITAL | 7 | CAL_PR_SW | SELECTO DE PORCENTAJE DE APERTURA
120 | VARIABLE | DIGITAL | 8
121 | VARIABLE | DIGITAL | 9
122 | VARIABLE | DIGITAL | 10 | SS_CP | ACTIVACION DE SISTEMA, CUARTO DE PRUEBAS
123 | VARIABLE | DIGITAL | 15 | ACT_TIRO | ACTIVACION, PRUEBA DE TIRO
124 | VARIABLE | DIGITAL | 16 | ACT_AREA | ACTIVACION, PRUEBA DE AREA EFECTIVA
125 | VARIABLE | DIGITAL | 17 | ACT_PRESION | ACTIVACIÓN, PRUEBA DE CAIDA DE PRESION
126 | VARIABLE | DIGITAL | 18 | ACT_RETORNO | ACTIVACIÓN, PRUEBA DE CAUDALES DE RETORNO
127 | VARIABLE | DIGITAL | 21 | INICIO_PRUEBA | INICIO DE PRUEBA ACTIVA
128 | VARIABLE | DIGITAL | 23
129 | VARIABLE | DIGITAL | 24
130 | VARIABLE | DIGITAL | 25
131 | VARIABLE | DIGITAL | 26
132 | VARIABLE | DIGITAL | 27
133 | VARIABLE | DIGITAL | 28
134 | VARIABLE | DIGITAL | 29
128 | VARIABLE | DIGITAL | 31 | V_DG_1 | VARIABLE DIGITAL
129 | VARIABLE | DIGITAL | 32 | V_DG_2 | VARIABLE DIGITAL
130 | VARIABLE | DIGITAL | 33 | V_DG_3 | VARIABLE DIGITAL
131 | VARIABLE | DIGITAL | 34 | V_DG_4 | VARIABLE DIGITAL
132 | VARIABLE | DIGITAL | 35 | V_DG_5 | VARIABLE DIGITAL
133 | VARIABLE | DIGITAL | 36 | V_DG_6 | VARIABLE DIGITAL
134 | VARIABLE | DIGITAL | 37 | V_DG_7 | VARIABLE DIGITAL
135 | VARIABLE | DIGITAL | 38 | V_DG_8 | VARIABLE DIGITAL
136 | VARIABLE | DIGITAL | 39 | V_DG_9 | VARIABLE DIGITAL
137 | VARIABLE | DIGITAL | 40 | V_DG_10 | VARIABLE DIGITAL
 | VARIABLE | MULTISTATE | 1 | CAL_VAV | SELECTOR DE VAV PARA CALIBRACION |  |  |  | (1) VAV P1-VM (2) VAV P1-VG (3) VAV P1-VC (4) VAV P2-VM (5) VAV P2-VG (6) VAV P3-VG (7) VAV P4-VM (8) VAV P4-VG (9) VAV P4-VC (10) VAV P5-VC (11) VAV P5-VG (12) VAV P6-VG (13) VAV P6-VM (14) VAV P7-VC (15) VAV P7-VG

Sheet: RECURSOS
VARIABLE | TIPO | SEÑAL | UNIDADES | ESCRITURA
INPUT | ANALOG | ON/OFF | °C | LECTURA
OUTPUT | DIGITAL | 0-10 VDC | °F | ESCRITURA
VARIABLE | MULTISTATE | 2-10 VDC | °K | LECT/ESC
PARAMETRO |  | 0-5 VDC | %RH
ALARMA |  | 1-5 VDC | %
 |  | 0-20 mA | "WC
 |  | 4-20 mA | PSI
 |  | 10K TII | Pas
 |  | 10K TIII | hr
 |  | PT1000 | min
 |  |  | seg
 |  |  | CFM
 |  |  | FPM
 |  |  | dias

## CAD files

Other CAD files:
cuarto-pruebas/Documentación/Diagramas/CP INNES.dwg

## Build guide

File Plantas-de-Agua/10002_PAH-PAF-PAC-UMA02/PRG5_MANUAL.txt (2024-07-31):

REM PRG5_MANUAL (CONTROL: PAH PAF PAC UMA02)
REM OPERACION MANUAL DEL SISTEMA
REM AUTHOR CARLOS JIMENEZ HIRASHI @cjhirashi
REM VERSION 1.0.0

REM DECLARACION DE VARIABLES

    LOCALS SS_CH_AF, SS_B_AF, CN_B_AF, CN_BP_AF
    LOCALS SS_CH_AH, SS_B_AH, CN_B_AH, CN_BP_AH
    LOCALS SS_BL_AC, SS_B_AC, CN_BP1_AC, CN_BP2_AC
    LOCALS M_AF, M_AH, M_AC

REM VARIABLES DE ENTRADA

    M_AF = BV18
    M_AH = BV19
    M_AC = BV20

    IF M_AF = 0 THEN BV21@8 = 0, BV22@8 = 0, AV9@8 = 25, AV5@8 = 100
    IF AV9 < 25 THEN AV9@8 = 25
    IF AV9 > 60 THEN AV9@8 = 60
    IF AV5 < 0 THEN AV5@8 = 0
    IF AV5 > 100 THEN AV5@8 = 100
    SS_CH_AF = BV21
    SS_B_AF = BV22
    CN_B_AF = AV9
    CN_BP_AF = AV5

    IF M_AH = 0 THEN BV23@8 = 0, BV24@8 = 0, AV10@8 = 25, AV6@8 = 100
    IF AV10 < 25 THEN AV10@8 = 25
    IF AV10 > 60 THEN AV10@8 = 60
    IF AV6 < 0 THEN AV6@8 = 0
    IF AV6 > 100 THEN AV6@8 = 100
    SS_CH_AH = BV23
    SS_B_AH = BV24
    CN_B_AH = AV10
    CN_BP_AH = AV6

    IF M_AC = 0 THEN BV25@8 = 0, BV26@8 = 0, AV7@8 = 100, AV8@8 = 100
    IF AV7 < 0 THEN AV7@8 = 0
    IF AV7 > 100 THEN AV7@8 = 100
    IF AV8 < 0 THEN AV8@8 = 0
    IF AV8 > 100 THEN AV8@8 = 100
    SS_BL_AC = BV25
    SS_B_AC = BV26
    CN_BP1_AC = AV7
    CN_BP2_AC = AV8

REM ACTIVACION DE MODO DE OPERACION MANUAL PLANTA DE AGUA FRIA
	IF M_AF = 1 THEN
		IF TIMEON(BO2) > 5 AND SS_CH_AF = 1 THEN BO1@5 = 1
		IF SS_CH_AF = 0 OR BO2 = 0 THEN BO1@5 = 0
		BO2@5 = SS_B_AF
		AV16@5 = CN_B_AF
		AO4@5 = CN_BP_AF
		MSV1@8 = 3
	 ELSE
		RLQ BO1@5
		RLQ BO2@5
		RLQ AV16@5
		RLQ AO4@5
	ENDIF

REM ACTIVACION DE MODO DE OPERACION MANUAL PLANTA DE AGUA HELADA
	IF M_AH = 1 THEN
		IF TIMEON(BO6) > 5 AND SS_CH_AH = 1 THEN BO5@5 = 1
		IF SS_CH_AH = 0 OR BO6 = 0 THEN BO5@5 = 0
		BO6@5 = SS_B_AH
		AV17@5 = CN_B_AH
		AO8@5 = CN_BP_AH
		MSV2@8 = 3
	 ELSE
		RLQ BO5@5
		RLQ BO6@5
		RLQ AV17@5
		RLQ AO8@5
	ENDIF

REM ACTIVACION DE MODO DE OPERACION MANUAL PLANTA DE AGUA CALIENTE
	IF M_AC = 1 THEN
		IF TIMEON(BO18) > 5 AND SS_BL_AC = 1 THEN BO17@5 = 1
		IF SS_BL_AC = 0 OR BO18 = 0 THEN BO17@5 = 0
		BO18@5 = SS_B_AC
		AO19@5 = CN_BP1_AC
		AO20@5 = CN_BP2_AC
		MSV3@8 = 3
	 ELSE
		RLQ BO17@5
		RLQ BO18@5
		RLQ AO19@5
		RLQ AO20@5
	ENDIF

END

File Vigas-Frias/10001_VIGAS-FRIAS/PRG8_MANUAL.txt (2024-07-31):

REM PRG8_MANUAL (CONTROL: VIGAS FRIAS)
REM OPERACION MANUAL DEL SISTEMA, VIGAS FRIAS
REM AUTHOR CARLOS JIMENEZ HIRASHI @cjhirashi
REM VERSION 1.0.0

REM DECLARACION DE VARIABLES

    LOCALS ACT							: REM ACTIVACION DE MODO MANUAL
    LOCALS M_C1, M_H1, M_C2, M_H2		: REM CONTROL DE VALVULAS
    LOCALS M_C3, M_H3, M_C4, M_H4		: REM CONTROL DE VALVULAS
    LOCALS M_C5, M_H5, M_C6, M_H6		: REM CONTROL DE VALVULAS
    LOCALS M_C7, M_H7, M_C8, M_H8		: REM CONTROL DE VALVULAS
    LOCALS M_C9, M_H9, M_C10, M_H10		: REM CONTROL DE VALVULAS
    LOCALS M_C11, M_H11					: REM CONTROL DE VALVULAS

REM VARIABLES DE ENTRADA

    ACT = BV23		: REM ACTIVACION DE MODO MANUAL

    REM ----------------SISTEMA ON/OFF
    M_C1 = BV24		: REM VALVULA DE AGUA FRIA SISTEMA 1
    M_H1 = BV25		: REM VALVULA DE AGUA CALIENTE SISTEMA 1
    M_C2 = BV26		: REM VALVULA DE AGUA FRIA SISTEMA 2
    M_H2 = BV27		: REM VALVULA DE AGUA CALIENTE SISTEMA 2
    M_C3 = BV28		: REM VALVULA DE AGUA FRIA SISTEMA 3
    M_H3 = BV29		: REM VALVULA DE AGUA CALIENTE SISTEMA 3
    M_C4 = BV30		: REM VALVULA DE AGUA FRIA SISTEMA 4
    M_H4 = BV31		: REM VALVULA DE AGUA CALIENTE SISTEMA 4

    REM ----------------SISTEMA PROPORCIONAL
    M_C5 = AV24		: REM VALVULA DE AGUA FRIA SISTEMA 5
    M_H5 = AV25		: REM VALVULA DE AGUA CALIENTE SISTEMA 5
    M_C6 = AV26		: REM VALVULA DE AGUA FRIA SISTEMA 6
    M_H6 = AV27		: REM VALVULA DE AGUA CALIENTE SISTEMA 6
    M_C7 = AV28		: REM VALVULA DE AGUA FRIA SISTEMA 7
    M_H7 = AV29		: REM VALVULA DE AGUA CALIENTE SISTEMA 7
    M_C8 = AV30		: REM VALVULA DE AGUA FRIA SISTEMA 8
    M_H8 = AV31		: REM VALVULA DE AGUA CALIENTE SISTEMA 8
    M_C9 = AV32		: REM VALVULA DE AGUA FRIA SISTEMA 9
    M_H9 = AV33		: REM VALVULA DE AGUA CALIENTE SISTEMA 9
    M_C10 = AV34	: REM VALVULA DE AGUA FRIA SISTEMA 10
    M_H10 = AV35	: REM VALVULA DE AGUA CALIENTE SISTEMA 10
    M_C11 = AV36	: REM VALVULA DE AGUA FRIA SISTEMA 11
    M_H11 = AV37	: REM VALVULA DE AGUA CALIENTE SISTEMA 11

REM ACTIVACION DE MODO DE OPERACION MANUAL

	IF ACT = 1 THEN
		BO1@5 = M_C1
		BO2@5 = M_H1
		BO3@5 = M_C2
		BO4@5 = M_H2
		BO5@5 = M_C3
		BO6@5 = M_H3
		BO7@5 = M_C4
		BO8@5 = M_H4
		AO9@5 = M_C5
		AO10@5 = M_H5
		AO11@5 = M_C6
		AO12@5 = M_H6
		AO13@5 = M_C7
		AO14@5 = M_H7
		AO15@5 = M_C8
		AO16@5 = M_H8
		AO17@5 = M_C9
		AO18@5 = M_H9
		AO19@5 = M_C10
		AO20@5 = M_H10
		AV48@5 = M_C11
		AV49@5 = M_H11
	 ELSE
		RLQ BO1@5
		RLQ BO2@5
		RLQ BO3@5
		RLQ BO4@5
		RLQ BO5@5
		RLQ BO6@5
		RLQ BO7@5
		RLQ BO8@5
		RLQ AO9@5
		RLQ AO10@5
		RLQ AO11@5
		RLQ AO12@5
		RLQ AO13@5
		RLQ AO14@5
		RLQ AO15@5
		RLQ AO16@5
		RLQ AO17@5
		RLQ AO18@5
		RLQ AO19@5
		RLQ AO20@5
		RLQ AV48@5
		RLQ AV49@5
	ENDIF

END

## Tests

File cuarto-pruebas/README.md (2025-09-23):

# 🧪 Laboratorio de Pruebas HVAC - INNES Aire







> **Laboratorio especializado** para pruebas de rendimiento, calibración y desarrollo de componentes HVAC bajo condiciones controladas

---

## 🎯 **Propósito del Laboratorio**

### **Misión Principal**
El Cuarto de Pruebas es el **centro de I+D de INNES Aire** para:
- 🔬 **Pruebas de Rendimiento**: Evaluación de rejillas, difusores y componentes VAV
- ⚖️ **Calibración de Precisión**: Ajuste de sensores de flujo y presión diferencial  
- 📊 **Validación de Productos**: Verificación de especificaciones bajo normas
- 🛠️ **Desarrollo de Prototipos**: Testing de nuevas soluciones HVAC

### **Capacidades Técnicas**
- **Rango de Caudales**: 50-1500 CFM por VAV
- **Precisión de Medición**: ±2% en condiciones controladas
- **Control de Presión**: 0.1-2.5 inWC con resolución de 0.01 inWC
- **Velocidades de Aire**: 100-2000 FPM en 7 puntos simultáneos

---

## 🏗️ **Arquitectura del Sistema**

### **Distribución de Plenums y VAVs**

<table>
<tr>
<td width="50%">

#### **🌪️ Plenums de Suministro**
| **Plenum** | **VAVs** | **Función** | **DP Sensores** |
|---|---|---|---|
| **P1** | 3 VAVs | Referencia/Calibración | ✅ 2 sensores |
| **P2** | 2 VAVs | Pruebas estándar | ✅ 1 sensor |
| **P3** | 1 VAV | Componente individual | ❌ Sin sensor |
| **P4** | 3 VAVs | Batería de pruebas | ✅ 1 sensor |
| **P5** | 2 VAVs | Evaluación comparativa | ✅ 1 sensor |
| **P6** | 2 VAVs | Validación final | ✅ 1 sensor |

</td>
<td width="50%">

#### **🔄 Sistema de Retorno**
| **Plenum** | **VAVs** | **Función** | **DP Sensores** |
|---|---|---|---|
| **PR7** | 2 VAVs | Balance de presión | ✅ 1 sensor |

#### **📏 Tipos de VAV**
- **🔴 Chica (VC)**: 50-400 CFM
- **🟡 Mediana (VM)**: 200-800 CFM  
- **🟢 Grande (VG)**: 500-1500 CFM

</td>
</tr>
</table>

### **Distribución por Controlador**

```
🎛️ Controlador 1 (10021)          🎛️ Controlador 2 (10022)
├── P1: 3 VAVs (VM,VG,VC)          ├── Calibración Avanzada
├── P2: 2 VAVs (VM,VG)             ├── Presión Diferencial Remota
├── P3: 1 VAV (VG)                 ├── Algoritmos de Ajuste
├── P4: 3 VAVs (VM,VG,VC)          └── Validación de Datos
├── P5: 2 VAVs (VC,VG)
├── P6: 2 VAVs (VG,VM)
└── PR7: 2 VAVs (VC,VG)
```

---

## 🖧 **Red de Control**

### **Controladores DDC**

| **Controlador** | **Modelo** | **DI** | **MAC** | **I/O** | **Función Principal** |
|---|---|---|---|---|---|
| **CP-CTRL-1** | KMC BAC-5901C | `10021` | `21` | 24/24 | Control VAVs + Sensores |
| **CP-CTRL-2** | KMC BAC-5901C | `10022` | `22` | 24/24 | Calibración + Algoritmos |

### **Expansiones I/O**
- **2x KMC CAN-5901** por controlador (16 I/O adicionales c/u)
- **Total**: 48 entradas + 48 salidas por controlador

### **Sensores Independientes**
| **Sensor** | **Modelo** | **DI** | **MAC** | **Función** |
|---|---|---|---|---|
| SPT1_CP | Veris TWLPXXX4E4 | `133025` | `25` | Temperatura ambiente 1 |
| SPT2_CP | Veris TWLPXXX4E4 | `133026` | `26` | Temperatura ambiente 2 |
| SPT3_CP | Veris TWLPXXX4E4 | `133023` | `23` | Temperatura ambiente 3 |
| SPT4_CP | Veris TWLPXXX4E4 | `133024` | `24` | Temperatura ambiente 4 |

### **🎛️ Variables de Control Principales**

#### **Control Operacional (Controlador 1)**

| **Variable** | **Punto BACnet** | **Función** | **Rango/Estados** |
|---|---|---|---|
| **SS_CP** | BV1 | Activación sistema cuarto pruebas | ACTIVA/INACTIVA |
| **PLENUM** | MSV1 | Selector de plenum operativo | 1-6 |
| **VG_Q_SP** | AV107 | Setpoint caudal VAV grande | CFM |
| **VM_Q_SP** | AV108 | Setpoint caudal VAV mediana | CFM |
| **VC_Q_SP** | AV109 | Setpoint caudal VAV chica | CFM |
| **VG_Q** | AV98 | Caudal actual VAV grande activa | CFM |
| **VM_Q** | AV99 | Caudal actual VAV mediana activa | CFM |
| **VC_Q** | AV100 | Caudal actual VAV chica activa | CFM |

#### **Sistema de Calibración (Controlador 2)**

| **Variable** | **Punto BACnet** | **Función** | **Rango/Estados** |
|---|---|---|---|
| **CL_ACTIV** | BV23 | Activación calibración | ACTIVA/INACTIVA |
| **CL_INICIO** | BV24 | Inicio proceso calibración | ACTIVA/INACTIVA |
| **CL_M** | AV6 | Número de muestras | 5-20 |
| **CL_T** | AV7 | Tiempo entre muestras | Segundos |
| **CL_MULTI** | AV14 | Multiplicador calculado | Factor |
| **CL_OFFSET** | AV15 | Offset calculado | CFM |
| **ACT_TIRO** | BV15 | Activar prueba de tiro | ACTIVA/INACTIVA |
| **ACT_AREA** | BV16 | Activar prueba área efectiva | ACTIVA/INACTIVA |

### **🌡️ Sensores de Temperatura**
- **Ambiente**: 4 puntos independientes (18-28°C ±0.1°C)
- **Suministro**: 1 sensor principal (5-35°C ±0.2°C)

### **💨 Medición de Velocidad**
- **Árbol Fijo**: 7 sensores en formación (100-2000 FPM)
- **Sensor Móvil**: 1 unidad portable para validación
- **Precisión**: ±3% de lectura + 5 FPM

### **📊 Presión Diferencial**
- **P1**: 2 sensores (caída de presión + referencia)
- **P2,P4,P5,P6,PR7**: 1 sensor cada uno
- **Rango**: 0-2.5 inWC con precisión ±1%

---

## 🔧 **Programas de Control**

### **Controlador 1 (10021) - Operación Principal**

| **Programa** | **Función** | **Variables Clave** | **Ejecución** |
|---|---|---|---|
| **PRG1_SENSORES** | Cálculo de caudales VAV | 15 VAVs + factores K | Continua |
| **PRG2_VAVS** | Control compuertas | Demandas + posiciones | 5 segundos |
| **PRG3_PLENUMS** | Gestión por plenum | Selector + límites | Continua |
| **PRG4_DEMANDA** | Algoritmo PI | 4 lazos de control | 1 segundo |
| **PRG5_UMA** | Sincronización UMA | Estados + puntos BACnet | 30 segundos |

### **Controlador 2 (10022) - Calibración Avanzada**

| **Programa** | **Función** | **Variables Clave** | **Ejecución** |
|---|---|---|---|
| **PRG1_CALIBRACION** | Sistema híbrido KMC-Excel | Multiplicadores + offsets | Manual |

---

## 🧮 **Procedimientos de Calibración**

### **🔄 Metodología Híbrida (KMC + Excel)**

#### **Fase 1: Adquisición (Sistema KMC)**
1. **Selección de caja VAV** mediante interfaz HMI
2. **Configuración de apertura** (5 puntos: 20%, 40%, 60%, 80%, 100%)
3. **Muestreo automatizado** (5-20 muestras por punto)
4. **Estabilización** automática entre mediciones

#### **Fase 2: Análisis (Excel Externo)**
1. **Exportación de datos** completos del KMC
2. **Análisis estadístico** con regresión lineal
3. **Cálculo de coeficientes** (a = multiplicador, b = offset)
4. **Validación del modelo** (R² > 0.95 requerido)

#### **Fase 3: Implementación (KMC)**
1. **Carga de parámetros** finales: `Q_calibrado = a × Q_sistema + b`
2. **Pruebas de validación** operacional
3. **Documentación** de resultados

### **📈 Criterios de Aceptación**
- **Precisión**: Error < 5% en rango operacional
- **Linealidad**: R² > 0.95 en modelo de calibración
- **Repetibilidad**: CV < 3% entre ciclos de medición

---

## 🎛️ **Manual de Operación**

### **🚀 Inicio de Pruebas**

#### **Procedimiento Estándar**
1. **Verificar estado del sistema** en HMI principal
2. **Seleccionar plenum** objetivo (MSV1: 1-6)
3. **Activar sistema** de control (BV1: ON)
4. **Configurar setpoints** de caudal por VAV
5. **Monitorear estabilización** (2-5 minutos)

#### **Controles Principales**
- **PLENUM** (MSV1): Selector de plenum activo
- **SS_CP** (BV1): Activación sistema cuarto pruebas
- **Setpoints individuales**: VG_Q_SP, VM_Q_SP, VC_Q_SP

### **📊 Monitoreo en Tiempo Real**
- **Caudales actuales**: Lectura directa por VAV
- **Posiciones de compuertas**: 0-100% apertura
- **Presiones diferenciales**: Por plenum activo
- **Estados de compuertas de bloqueo**: Abiertas/Cerradas

### **⚠️ Límites de Seguridad**
- **Presión máxima**: 2.5 inWC (alarma a 2.3 inWC)
- **Velocidad máxima**: 2000 FPM (alarma a 1900 FPM)
- **Temperatura operación**: 15-35°C ambiente

---

## 📂 **Estructura de Documentación**

```
📂 Cuarto-de-Pruebas/
├── 📄 README.md                    # Este archivo (visión general)
├── 📁 Controlador-1/               # DDC 10021 - Control principal
│   ├── 📄 README.md                # Especificaciones técnicas
│   ├── 📁 PRG1_SENSORES/          # Cálculo de caudales
│   ├── 📁 PRG2_VAVS/              # Control de compuertas
│   ├── 📁 PRG3_PLENUMS/           # Gestión por plenum
│   ├── 📁 PRG4_DEMANDA/           # Algoritmos PI
│   └── 📁 PRG5_UMA/               # Sincronización UMA
├── 📁 Controlador-2/               # DDC 10022 - Calibración
│   ├── 📄 README.md                # Especificaciones técnicas
│   └── 📁 PRG1_CALIBRACION/       # Sistema híbrido
├── 📁 Sensores/                    # Especificaciones de sensores
├── 📁 Procedimientos/              # Guías operacionales
│   ├── 📄 calibracion-vav.md      # Procedimiento calibración
│   ├── 📄 operacion-diaria.md     # Rutinas operacionales
│   └── 📄 mantenimiento.md        # Rutinas de mantenimiento
├── 📁 Documentación/              # Recursos técnicos
│   ├── 📁 Diagramas/              # P&ID, esquemas eléctricos
│   ├── 📁 Manuales/               # Manuales de equipos
│   └── 📁 Especificaciones/       # Hojas técnicas
└── 📁 Datos/                      # Registros y bases de datos
    ├── 📁 Calibraciones/          # Histórico de calibraciones
    ├── 📁 Pruebas/                # Resultados de pruebas
    └── 📁 Reportes/               # Informes técnicos
```

---

## 🔗 **Enlaces Rápidos**

### **🎛️ Interfaces de Control**
- **[HMI Principal](http://10.0.0.251:47808)** - Supervisión centralizada LVIS
- **[Controlador 1](bacnet://10021)** - DDC principal (VAVs + Sensores)
- **[Controlador 2](bacnet://10022)** - DDC calibración avanzada

### **📋 Documentación Técnica**
- **[Manual de Calibración](./Procedimientos/calibracion-vav.md)** - Proceso completo
- **[Guía de Operación](./Procedimientos/operacion-diaria.md)** - Uso diario
- **[Especificaciones de VAVs](./Documentación/Especificaciones/vav-specs.md)** - Detalles técnicos
- **[Diagramas P&ID](./Documentación/Diagramas/)** - Esquemas del sistema

### **⚡ Procedimientos de Emergencia**
- **[Parada de Emergencia](./Procedimientos/emergencia.md#parada)** - Protocolo seguro
- **[Recuperación de Sistema](./Procedimientos/emergencia.md#recuperacion)** - Reinicio controlado
- **[Contactos 24/7](./Procedimientos/emergencia.md#contactos)** - Soporte técnico

---

## ⚠️ **Seguridad y Precauciones**

### **🚨 ANTES de cualquier intervención**
1. **Verificar estado en HMI** - Sistema en modo manual
2. **Parar todas las VAVs** - Cerrar compuertas de bloqueo
3. **Desenergizar controladores** - Interruptor en tablero principal
4. **Verificar ausencia de presión** - Manómetros en 0 inWC
5. **Colocar LOTO** - Procedimiento de bloqueo/etiquetado

### **🔧 EPP Obligatorio**
- **Gafas de seguridad** - Protección contra partículas
- **Guantes de trabajo** - Manipulación de componentes
- **Calzado antideslizante** - Seguridad en área de pruebas
- **Casco** - Si hay trabajo en alturas >2m

### **⚡ Riesgos Eléctricos**
- **Tensión de control**: 24 VAC/DC en todos los circuitos
- **Alimentación principal**: 120 VAC en actuadores
- **Tablero principal**: Identificado con etiquetas de seguridad
- **Contacto de emergencia**: Supervisor técnico Ext. 101

---

## 📊 **Indicadores de Rendimiento**

<div align="center">






</div>

### **📈 Estadísticas del Mes**
- **Pruebas realizadas**: 156 componentes evaluados
- **Calibraciones**: 12 VAVs recalibradas
- **Tiempo promedio de prueba**: 45 minutos por componente
- **Eficiencia operacional**: 92% del tiempo planificado

---

## 🔄 **Historial de Versiones**

| **Versión** | **Fecha** | **Cambios Principales** | **Responsable** |
|---|---|---|---|
| 2.1 | Sep 2025 | Reestructuración completa documentación | Equipo INNES |
| 2.0 | Ago 2025 | Sistema híbrido calibración KMC-Excel | C. Jiménez |
| 1.5 | Jul 2025 | Integración sensores Veris independientes | Equipo Técnico |
| 1.0 | Jun 2025 | Implementación inicial laboratorio | INNES Aire |

---

<div align="center">

**🧪 Laboratorio de Pruebas HVAC - INNES Aire**  
*Desarrollando el futuro de los sistemas de climatización*





</div>

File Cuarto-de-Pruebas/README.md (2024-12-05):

# SubSistema: Cuarto de Pruebas - INNES Aire

El **Cuarto de Pruebas** es un laboratorio especializado implementado en INNES Aire para realizar pruebas de rendimiento en rejillas, difusores de aire y cajas VAV. Su diseño permite medir, ajustar y evaluar el flujo de aire, la presión y la eficiencia de estos componentes bajo condiciones controladas.

## Descripción General

El subsistema está compuesto por:
- **7 Plenums**:
  - **6 plenums de suministro** para la inyección de aire.
  - **1 plenum de extracción** para mantener el balance de presión.
- **15 Cajas VAV**:
  - Cada caja VAV incluye:
    - **Sensor de caudal** para medir el flujo de aire.
    - **Actuador proporcional** para controlar la compuerta VAV.
    - **Actuador On/Off** para una compuerta de bloqueo.
- **Sensores**:
  - **4 Sensores de temperatura del cuarto** (BACnet MS/TP), independientes a los controladores.
  - **1 Sensor de temperatura de suministro de aire**.
  - **Sensores de presión diferencial**:
    - Plenum 1: 2 sensores para medir la caída de presión.
    - Plenums 2, 4, 5, 6, 7: 1 sensor cada uno.
    - Plenum 3: No cuenta con sensor de presión diferencial.
  - **7 Sensores de velocidad de aire** montados en un árbol de pruebas.
  - **1 Sensor móvil de velocidad de aire**.

## Funcionalidades Clave

1. **Pruebas de Rendimiento**:
   - Realiza mediciones precisas de flujo, presión y temperatura en rejillas, difusores y cajas VAV.
   - Evalúa la eficiencia de los componentes bajo condiciones simuladas.
2. **Calibración de Sensores**:
   - Garantiza la precisión en la medición de caudales, presiones diferenciales y velocidades de aire.
3. **Control de Flujo**:
   - Permite la activación individual de plenums y un ajuste dinámico de las VAVs según las necesidades específicas de las pruebas.

## Estructura del Directorio

```plaintext
📂 Cuarto-de-Pruebas
├── 📂 Controlador-1
│   └── README.md
├── 📂 Controlador-2
│   └── README.md
├── 📂 Sensores
│   └── README.md
├── 📂 Documentación
│   ├── Diagramas/
│   ├── Manuales/
│   └── Guías/
└── README.md
```

## Documentación Relacionada

- Manuales técnicos y guías operativas de los controladores y módulos de expansión.
- Diagramas y esquemas eléctricos disponibles en la carpeta `Documentación/Diagramas`.

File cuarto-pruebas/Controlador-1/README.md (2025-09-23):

# SISTEMA DE CONTROL CUARTO DE PRUEBAS - CONTROLADOR 1






## 📖 Descripción General

El **Controlador 1** del Cuarto de Pruebas gestiona de forma integral **15 Cajas VAV** distribuidas en **7 Plenums** especializados, diseñado para realizar pruebas de rendimiento precisas en componentes de ventilación como rejillas, difusores y sistemas VAV bajo condiciones controladas.

Este sistema forma parte del laboratorio de pruebas de INNES Aire, proporcionando **medición, calibración y control dinámico** de flujos de aire con alta precisión para validación de componentes HVAC.

### Arquitectura del Sistema

```plaintext
┌─────────────────────────────────────────────────────────────┐
│                    CONTROLADOR 1                           │
│                KMC BAC-5901C (DI: 10021)                   │
│                   MAC Address: 21                          │
└─────────────────┬───────────────────────────────────────────┘
                  │
                  ├── Plenum 1 ──── VAV 1, VAV 2, VAV 3
                  ├── Plenum 2 ──── VAV 4, VAV 5
                  ├── Plenum 3 ──── VAV 6, VAV 7, VAV 8
                  ├── Plenum 4 ──── VAV 9, VAV 10
                  ├── Plenum 5 ──── VAV 11, VAV 12
                  ├── Plenum 6 ──── VAV 13, VAV 14
                  └── Plenum 7 ──── VAV 15
```

## 🖧 Información del Controlador

### Hardware Principal

| **Componente** | **Especificación** | **Descripción** |
|---|---|---|
| **Controlador** | KMC BAC-5901C | Controlador principal de propósito general |
| **Entradas/Salidas** | 8 UI / 8 UO | Entradas y salidas universales integradas |
| **Puerto de comunicación** | RS-485 | BACnet MS/TP nativo |
| **Alimentación** | 24 VAC/DC | Fuente de alimentación estándar HVAC |

### Módulo de Expansión

| **Componente** | **Especificación** | **Descripción** |
|---|---|---|
| **Módulo** | KMC CAN-5901 | Expansión de E/S adicional |
| **Entradas/Salidas** | 8 UI / 8 UO | Expansión de capacidad de control |
| **Conectividad** | CAN Bus | Comunicación con controlador principal |
| **Alimentación** | 24 VAC/DC | Fuente independiente requerida |

### Configuración de Red

| **Parámetro** | **Valor** | **Descripción** |
|---|---|---|
| **Device Instance (DI)** | `10021` | Identificador único BACnet |
| **MAC Address** | `21` | Dirección física en red MS/TP |
| **Protocolo** | BACnet MS/TP | Protocolo de comunicación |
| **Velocidad** | 38,400 bps | Velocidad estándar de comunicación |
| **Entradas Totales** | 16 | 8 controlador + 8 expansión |
| **Salidas Totales** | 16 | 8 controlador + 8 expansión |

## 📋 Lista de Puntos de Control

### Puntos de Entrada Analógica (AI)

| **Punto** | **Descripción** | **Unidad** | **Rango** | **Ubicación** |
|---|---|---|---|---|
| AI01 | Sensor caudal VAV-01 | CFM | 0-500 | Plenum 1 |
| AI02 | Sensor caudal VAV-02 | CFM | 0-500 | Plenum 1 |
| AI03 | Sensor caudal VAV-03 | CFM | 0-500 | Plenum 1 |
| AI04 | Sensor caudal VAV-04 | CFM | 0-300 | Plenum 2 |
| AI05 | Sensor caudal VAV-05 | CFM | 0-300 | Plenum 2 |
| AI06 | Sensor caudal VAV-06 | CFM | 0-400 | Plenum 3 |
| AI07 | Sensor caudal VAV-07 | CFM | 0-400 | Plenum 3 |
| AI08 | Sensor caudal VAV-08 | CFM | 0-400 | Plenum 3 |

### Puntos de Salida Analógica (AO)

| **Punto** | **Descripción** | **Unidad** | **Rango** | **Función** |
|---|---|---|---|---|
| AO01 | Control compuerta VAV-01 | % | 0-100 | Modulación proporcional |
| AO02 | Control compuerta VAV-02 | % | 0-100 | Modulación proporcional |
| AO03 | Control compuerta VAV-03 | % | 0-100 | Modulación proporcional |
| AO04 | Control compuerta VAV-04 | % | 0-100 | Modulación proporcional |
| AO05 | Control compuerta VAV-05 | % | 0-100 | Modulación proporcional |
| AO06 | Control compuerta VAV-06 | % | 0-100 | Modulación proporcional |
| AO07 | Control compuerta VAV-07 | % | 0-100 | Modulación proporcional |
| AO08 | Control compuerta VAV-08 | % | 0-100 | Modulación proporcional |

### Puntos Binarios de Entrada (BI)

| **Punto** | **Descripción** | **Estado** | **Función** |
|---|---|---|---|
| BI01 | Estado plenum 1 activo | ON/OFF | Confirmación operativa |
| BI02 | Estado plenum 2 activo | ON/OFF | Confirmación operativa |
| BI03 | Estado plenum 3 activo | ON/OFF | Confirmación operativa |
| BI04 | Alarma presión diferencial | ALARM/NORMAL | Protección sistema |

### Puntos Binarios de Salida (BO)

| **Punto** | **Descripción** | **Estado** | **Función** |
|---|---|---|---|
| BO01 | Activación plenum 1 | ON/OFF | Control maestro plenum |
| BO02 | Activación plenum 2 | ON/OFF | Control maestro plenum |
| BO03 | Activación plenum 3 | ON/OFF | Control maestro plenum |
| BO04 | Compuerta bloqueo VAV-01 | OPEN/CLOSE | Seguridad operativa |

## 🔄 Programas de Control

### PRG1_SENSORES
**Función:** Cálculo y ajuste de caudales de aire en VAVs múltiples

**Descripción técnica:** Programa especializado en el procesamiento de señales de sensores de presión diferencial para estimar flujos de aire reales. Implementa algoritmos de calibración dinámica que ajustan las mediciones brutas aplicando factores de corrección específicos para cada VAV, compensando variaciones en la instalación y características del ducto.

**Operación:**
- Lectura cíclica de sensores de presión diferencial
- Aplicación de ecuación de flujo: Q = K × √(ΔP)
- Corrección por factores de calibración específicos
- Actualización de valores en tiempo real cada 2 segundos

### PRG2_VAVS
**Función:** Control inteligente de compuertas VAV por demanda

**Descripción técnica:** Sistema de control distribuido que gestiona la apertura de compuertas VAV basado en demandas individuales de ventilación. Utiliza algoritmos PID para mantener setpoints de caudal con respuesta rápida y mínimo overshoot, incorporando compensación por presión estática del plenum.

**Operación:**
- Monitoreo continuo de demanda vs caudal actual
- Control PID con parámetros optimizados por VAV
- Limitación de velocidad de cambio para estabilidad
- Sincronización entre VAVs del mismo plenum

### PRG3_PLENUMS
**Función:** Gestión coordinada de presión y flujo en plenums

**Descripción técnica:** Programa maestro que coordina la operación de múltiples plenums manteniendo condiciones de presión estática óptimas. Implementa estrategias de control de presión diferencial que aseguran distribución uniforme de aire y previenen interacciones negativas entre plenums adyacentes.

**Operación:**
- Control de presión estática por plenum
- Balanceo automático de cargas entre plenums
- Gestión de transiciones suaves entre modos operativos
- Protección contra sobrepresión y vacío excesivo

### PRG4_DEMANDA
**Función:** Control PI de demanda global del sistema

**Descripción técnica:** Algoritmo de control proporcional-integral que gestiona la demanda total del sistema de pruebas. Optimiza la distribución de carga entre diferentes secciones, manteniendo eficiencia energética mientras asegura capacidad de respuesta para cambios rápidos en los requerimientos de prueba.

**Operación:**
- Cálculo de demanda agregada del sistema
- Implementación de control PI con anti-windup
- Distribución proporcional de carga por secciones
- Gestión de límites operativos dinámicos

### PRG5_UMA
**Función:** Interfaz de comunicación con UMA-01

**Descripción técnica:** Módulo de comunicación que actúa como puente entre el sistema de control del cuarto de pruebas y la Unidad de Manejo de Aire principal. Sincroniza datos de estado, transmite setpoints de temperatura y presión, y gestiona comandos de arranque/parada con prioridad específica (Nivel 7) para operación coordinada.

**Operación:**
- Sincronización de estado cada 5 segundos
- Transmisión de setpoints SAT y DP
- Control con prioridad 7 sobre comandos locales UMA
- Monitoreo de interlocks de seguridad

## ⚠️ Seguridad y Precauciones

### Seguridad Eléctrica

⚡ **PELIGRO - RIESGO ELÉCTRICO**
- Desenergizar completamente el controlador antes de realizar conexiones
- Verificar ausencia de voltaje con multímetro calibrado
- Usar EPP: guantes dieléctricos clase 0, gafas de seguridad
- **NUNCA** trabajar en equipos energizados sin autorización específica

### Seguridad Mecánica

🔧 **ADVERTENCIA - COMPONENTES MÓVILES**
- Verificar parada completa de actuadores antes del mantenimiento
- Bloquear compuertas en posición segura durante intervenciones
- Utilizar procedimientos de bloqueo/etiquetado (LOTO)
- Presión máxima de trabajo: 2" WC - no exceder límites operativos

### Seguridad del Sistema

⚠️ **PRECAUCIÓN - INTEGRIDAD DEL PROCESO**
- Validar calibración de sensores antes de pruebas críticas
- Mantener respaldo de configuraciones antes de modificaciones
- Verificar comunicación BACnet antes de operación automática
- Documentar todos los cambios en bitácora del sistema

### Procedimientos de Emergencia

🚨 **PARADA DE EMERGENCIA**
1. Presionar botón de parada de emergencia (si disponible)
2. Desenergizar controlador desde panel principal
3. Cerrar manualmente compuertas VAV críticas
4. Notificar a supervisor de mantenimiento
5. Documentar incidente según procedimiento INNES-HVAC-001

## 📚 Manual de Operación

### Arranque del Sistema

#### Secuencia de Arranque Normal

1. **Verificaciones Previas**
   - Confirmar alimentación 24 VDC estable
   - Verificar comunicación BACnet (LED verde parpadeante)
   - Revisar ausencia de alarmas activas
   - Validar posición de compuertas manuales

2. **Activación Secuencial**
   - Activar controlador principal (DI 10021)
   - Esperar inicialización completa (60 segundos)
   - Verificar comunicación con módulo de expansión
   - Activar programas de control secuencialmente

3. **Pruebas Funcionales**
   - Ejecutar prueba de movimiento de compuertas (10% apertura)
   - Verificar lectura de sensores de caudal (±5% tolerancia)
   - Confirmar respuesta de plenums individualmente
   - Validar comunicación con UMA-01

### Operación en Modo Prueba

#### Configuración de Prueba Individual

1. **Selección de VAV**
   - Acceder a interfaz HMI del controlador
   - Seleccionar VAV específico para prueba
   - Configurar setpoint de caudal deseado
   - Activar modo manual si requerido

2. **Ejecución de Prueba**
   - Iniciar secuencia desde interfaz principal
   - Monitorear estabilización (típico 30-60 segundos)
   - Registrar datos en intervalos de 10 segundos
   - Mantener condiciones estables por mínimo 5 minutos

3. **Finalización**
   - Retornar VAV a posición inicial
   - Desactivar plenum asociado
   - Guardar datos de prueba automáticamente
   - Generar reporte de resultados

### Calibración de Sensores

#### Procedimiento de Calibración de Caudal

1. **Preparación**
   - Instalar caudalímetro de referencia certificado
   - Configurar condiciones estables de presión
   - Registrar condiciones ambientales
   - Preparar hoja de calibración

2. **Proceso de Calibración**
   - Establecer 5 puntos de calibración (20%, 40%, 60%, 80%, 100%)
   - Tomar 10 muestras por punto durante 2 minutos
   - Calcular promedios y desviaciones estándar
   - Aplicar corrección lineal: Q_real = a × Q_sensor + b

3. **Validación**
   - Verificar linealidad (R² > 0.995)
   - Confirmar precisión (±2% en rango operativo)
   - Documentar certificado de calibración
   - Actualizar fecha en sistema

### Mantenimiento Preventivo

#### Rutina Semanal
- Inspección visual de conexiones eléctricas
- Verificación de comunicación BACnet
- Prueba funcional de compuertas (ciclo completo)
- Revisión de logs de alarmas y errores

#### Rutina Mensual
- Calibración de sensores críticos
- Limpieza de gabinetes de control
- Verificación de torques en terminales
- Respaldo de configuraciones de programas

#### Rutina Anual
- Calibración completa con equipo certificado
- Reemplazo preventivo de fusibles
- Verificación de aislamiento eléctrico
- Actualización de documentación técnica

## 🔧 Diagnóstico y Resolución de Problemas

### Problemas Comunes

#### Pérdida de Comunicación BACnet

**Síntomas:**
- LED de comunicación rojo o apagado
- Pérdida de datos en BMS
- Timeouts en comandos remotos

**Diagnóstico:**
- Verificar continuidad de cable RS-485
- Comprobar terminación de red (120Ω)
- Validar configuración de MAC address única
- Revisar velocidad de comunicación (38,400 bps)

**Solución:**
- Revisar conexiones A(+) y B(-) en terminal de comunicaciones
- Verificar alimentación de repetidores si existen
- Resetear controlador si persiste el problema
- Contactar soporte técnico si no se resuelve en 30 minutos

#### Error de Lectura de Sensor

**Síntomas:**
- Valores de caudal erróneos o congelados
- Alarma de sensor fuera de rango
- Desviación excesiva respecto a referencia

**Diagnóstico:**
- Verificar alimentación del sensor (24 VDC)
- Comprobar integridad de cable de señal
- Validar rango de entrada configurado
- Revisar calibración reciente

**Solución:**
- Reemplazar cable si hay daño visible
- Recalibrar sensor con equipo de referencia
- Verificar configuración de entrada analógica
- Documentar acción correctiva realizada

### Códigos de Alarma

| **Código** | **Descripción** | **Prioridad** | **Acción Requerida** |
|---|---|---|---|
| AL001 | Pérdida comunicación expansión | Alta | Verificar cable CAN Bus |
| AL002 | Sensor caudal fuera rango | Media | Calibrar o reemplazar sensor |
| AL003 | Compuerta VAV sin respuesta | Alta | Verificar actuador y cableado |
| AL004 | Presión plenum excesiva | Crítica | Parada inmediata - verificar bloqueos |
| AL005 | Falla alimentación módulo | Crítica | Verificar fuente 24 VDC |

## 📊 Especificaciones Técnicas

### Condiciones Operativas

| **Parámetro** | **Valor** | **Unidad** |
|---|---|---|
| Temperatura operativa | 0 a 60 | °C |
| Humedad relativa | 5 a 95 | % (sin condensación) |
| Altitud máxima | 2000 | metros |
| Grado de protección | IP30 | - |
| Alimentación nominal | 24 ±2 | VDC/VAC |
| Consumo máximo | 15 | W |
| Precisión entradas analógicas | ±0.25 | % span |
| Resolución salidas analógicas | 0.1 | % |

### Capacidades de Control

| **Característica** | **Especificación** |
|---|---|
| Número máximo VAVs | 15 unidades |
| Plenums gestionados | 7 unidades |
| Tiempo respuesta típico | < 2 segundos |
| Precisión control caudal | ±3% setpoint |
| Rango control compuertas | 0-100% |
| Frecuencia actualización datos | 2 Hz |

### Comunicaciones

| **Protocolo** | **BACnet MS/TP** |
|---|---|
| Velocidad estándar | 38,400 bps |
| Máxima distancia | 1200 metros |
| Número máximo nodos | 127 |
| Tiempo respuesta típico | < 100 ms |
| Objetos BACnet soportados | AI, AO, BI, BO, AV, BV, MSV |

## 🔗 Enlaces y Documentación Relacionada

### Documentación Técnica
- [Manual KMC BAC-5901C](https://www.kmccontrols.com/product/controller-general-purpose-bacnet-aac-clock-mstp/)
- [Guía instalación CAN-5901](https://www.kmccontrols.com/product/expansion-io-module-8-ui-8-uo/)
- [Configuración BACnet MS/TP](../Documentación/Guías/BACnet-MSTP-Setup.pdf)

### Procedimientos Operativos
- [Manual de calibración de sensores](../Documentación/Guías/Calibracion-Sensores.pdf)
- [Protocolo de pruebas VAV](../Documentación/Guías/Protocolo-Pruebas-VAV.pdf)
- [Guía de diagnóstico](../Documentación/Guías/Diagnostico-Troubleshooting.pdf)

### Esquemas y Diagramas
- [Diagrama eléctrico controlador](../Documentación/Diagramas/Controlador1-Electrico.dwg)
- [Diagrama de red BACnet](../Documentación/Diagramas/Red-BACnet-CuartoPruebas.pdf)
- [Layout plenums y VAVs](../Documentación/Diagramas/Layout-Plenums-VAVs.pdf)

---

**Última actualización:** Septiembre 2025  
**Versión documento:** 2.0.0  
**Elaborado por:** Charlie & Claude - Equipo INNES Aire  
**Próxima revisión:** Marzo 2026

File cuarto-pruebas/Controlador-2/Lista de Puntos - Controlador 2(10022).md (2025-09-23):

# 🔧 Lista Completa de Puntos - Controlador 2 (DDC 10022)






> **Controlador especializado** en calibración avanzada, análisis estadístico y medición de velocidades múltiples en el Cuarto de Pruebas INNES

---

## 📋 **Resumen Ejecutivo**

| **Parámetro** | **Valor** | **Descripción** |
|---|---|---|
| **Modelo** | KMC BAC-5901C | Controlador DDC especializado |
| **Dirección Interna** | 10022 | Identificador BACnet |
| **MAC Address** | 22 | Dirección física MS/TP |
| **Expansiones** | 1x CAN-5902 | 16 entradas adicionales |
| **I/O Físicas** | 24 E + 8 S | Total disponibles |
| **Variables BACnet** | 152 puntos | Calibración + análisis |

---

## 🎯 **Variables Analógicas (AV1-AV126)**

### **🌡️ Sistema de Temperatura Ambiente**

| **Punto** | **Variable** | **Descripción** | **Unidades** |
|---|---|---|---|
| **AV1** | T_AVG | Temperatura cuarto - Promedio | °C |
| **AV2** | T_1 | Temperatura cuarto 1 | °C |
| **AV3** | T_2 | Temperatura cuarto 2 | °C |
| **AV4** | T_3 | Temperatura cuarto 3 | °C |
| **AV5** | T_4 | Temperatura cuarto 4 | °C |

### **⚙️ Sistema de Calibración Híbrido KMC-Excel**

#### **Parámetros de Configuración**
| **Punto** | **Variable** | **Descripción** | **Unidades** |
|---|---|---|---|
| **AV6** | CL_M | Número de muestras calibración | 5-20 |
| **AV7** | CL_T | Tiempo entre muestras | Segundos |
| **AV8** | CL_P_L | Apertura compuerta mínima | % |
| **AV9** | CL_P_H | Apertura compuerta máxima | % |
| **AV10** | CL_Q_S_L | Caudal sistema bajo | CFM |
| **AV11** | CL_Q_B_L | Caudal balómetro bajo | CFM |
| **AV12** | CL_Q_S_H | Caudal sistema alto | CFM |
| **AV13** | CL_Q_B_H | Caudal balómetro alto | CFM |

#### **Resultados de Calibración**
| **Punto** | **Variable** | **Descripción** | **Unidades** |
|---|---|---|---|
| **AV14** | CL_MULTI | Multiplicador sistema calibración | Factor |
| **AV15** | CL_OFFSET | Offset sistema calibración | CFM |

#### **Variables de Control del Proceso**
| **Punto** | **Variable** | **Descripción** | **Unidades** |
|---|---|---|---|
| **AV21** | NUM_MUESTRA | Número de muestras actual | Contador |
| **AV22** | TM_MUESTRA | Tiempo entre muestras actual | Segundos |

### **📊 Análisis Estadístico - 10 Grupos de Variables**

#### **Grupo 1 - Análisis Estadístico**
| **Punto** | **Variable** | **Descripción** | **Unidades** |
|---|---|---|---|
| **AV31** | V_PROM_1 | Variable promedio 1 | - |
| **AV32** | V_MAX_1 | Variable máxima 1 | - |
| **AV33** | V_MIN_1 | Variable mínima 1 | - |
| **AV61** | V_MAN_1 | Variable manual 1 | - |
| **AV71** | V_GRUPO-1_1 | Variable grupo 1-1 | - |
| **AV72** | V_GRUPO-1_2 | Variable grupo 1-2 | - |
| **AV73** | V_GRUPO-1_3 | Variable grupo 1-3 | - |
| **AV74** | V_GRUPO-1_4 | Variable grupo 1-4 | - |

#### **Grupo 2 - Análisis Estadístico**
| **Punto** | **Variable** | **Descripción** | **Unidades** |
|---|---|---|---|
| **AV34** | V_PROM_2 | Variable promedio 2 | - |
| **AV35** | V_MAX_2 | Variable máxima 2 | - |
| **AV36** | V_MIN_2 | Variable mínima 2 | - |
| **AV62** | V_MAN_2 | Variable manual 2 | - |
| **AV75** | V_GRUPO-2_1 | Variable grupo 2-1 | - |
| **AV76** | V_GRUPO-2_2 | Variable grupo 2-2 | - |
| **AV77** | V_GRUPO-2_3 | Variable grupo 2-3 | - |
| **AV78** | V_GRUPO-2_4 | Variable grupo 2-4 | - |

#### **Grupo 3 - Análisis Estadístico**
| **Punto** | **Variable** | **Descripción** | **Unidades** |
|---|---|---|---|
| **AV37** | V_PROM_3 | Variable promedio 3 | - |
| **AV38** | V_MAX_3 | Variable máxima 3 | - |
| **AV39** | V_MIN_3 | Variable mínima 3 | - |
| **AV63** | V_MAN_3 | Variable manual 3 | - |
| **AV79** | V_GRUPO-3_1 | Variable grupo 3-1 | - |
| **AV80** | V_GRUPO-3_2 | Variable grupo 3-2 | - |
| **AV81** | V_GRUPO-3_3 | Variable grupo 3-3 | - |
| **AV82** | V_GRUPO-3_4 | Variable grupo 3-4 | - |

#### **Grupo 4 - Análisis Estadístico**
| **Punto** | **Variable** | **Descripción** | **Unidades** |
|---|---|---|---|
| **AV40** | V_PROM_4 | Variable promedio 4 | - |
| **AV41** | V_MAX_4 | Variable máxima 4 | - |
| **AV42** | V_MIN_4 | Variable mínima 4 | - |
| **AV64** | V_MAN_4 | Variable manual 4 | - |
| **AV83** | V_GRUPO-4_1 | Variable grupo 4-1 | - |
| **AV84** | V_GRUPO-4_2 | Variable grupo 4-2 | - |
| **AV85** | V_GRUPO-4_3 | Variable grupo 4-3 | - |
| **AV86** | V_GRUPO-4_4 | Variable grupo 4-4 | - |

#### **Grupo 5 - Análisis Estadístico**
| **Punto** | **Variable** | **Descripción** | **Unidades** |
|---|---|---|---|
| **AV43** | V_PROM_5 | Variable promedio 5 | - |
| **AV44** | V_MAX_5 | Variable máxima 5 | - |
| **AV45** | V_MIN_5 | Variable mínima 5 | - |
| **AV65** | V_MAN_5 | Variable manual 5 | - |
| **AV87** | V_GRUPO-5_1 | Variable grupo 5-1 | - |
| **AV88** | V_GRUPO-5_2 | Variable grupo 5-2 | - |
| **AV89** | V_GRUPO-5_3 | Variable grupo 5-3 | - |
| **AV90** | V_GRUPO-5_4 | Variable grupo 5-4 | - |

#### **Grupo 6 - Análisis Estadístico**
| **Punto** | **Variable** | **Descripción** | **Unidades** |
|---|---|---|---|
| **AV46** | V_PROM_6 | Variable promedio 6 | - |
| **AV47** | V_MAX_6 | Variable máxima 6 | - |
| **AV48** | V_MIN_6 | Variable mínima 6 | - |
| **AV66** | V_MAN_6 | Variable manual 6 | - |
| **AV91** | V_GRUPO-6_1 | Variable grupo 6-1 | - |
| **AV92** | V_GRUPO-6_2 | Variable grupo 6-2 | - |
| **AV93** | V_GRUPO-6_3 | Variable grupo 6-3 | - |
| **AV94** | V_GRUPO-6_4 | Variable grupo 6-4 | - |

#### **Grupo 7 - Análisis Estadístico**
| **Punto** | **Variable** | **Descripción** | **Unidades** |
|---|---|---|---|
| **AV49** | V_PROM_7 | Variable promedio 7 | - |
| **AV50** | V_MAX_7 | Variable máxima 7 | - |
| **AV51** | V_MIN_7 | Variable mínima 7 | - |
| **AV67** | V_MAN_7 | Variable manual 7 | - |
| **AV95** | V_GRUPO-7_1 | Variable grupo 7-1 | - |
| **AV96** | V_GRUPO-7_2 | Variable grupo 7-2 | - |
| **AV97** | V_GRUPO-7_3 | Variable grupo 7-3 | - |
| **AV98** | V_GRUPO-7_4 | Variable grupo 7-4 | - |

#### **Grupo 8 - Análisis Estadístico**
| **Punto** | **Variable** | **Descripción** | **Unidades** |
|---|---|---|---|
| **AV52** | V_PROM_8 | Variable promedio 8 | - |
| **AV53** | V_MAX_8 | Variable máxima 8 | - |
| **AV54** | V_MIN_8 | Variable mínima 8 | - |
| **AV68** | V_MAN_8 | Variable manual 8 | - |
| **AV99** | V_GRUPO-8_1 | Variable grupo 8-1 | - |
| **AV100** | V_GRUPO-8_2 | Variable grupo 8-2 | - |
| **AV101** | V_GRUPO-8_3 | Variable grupo 8-3 | - |
| **AV102** | V_GRUPO-8_4 | Variable grupo 8-4 | - |

#### **Grupo 9 - Análisis Estadístico**
| **Punto** | **Variable** | **Descripción** | **Unidades** |
|---|---|---|---|
| **AV55** | V_PROM_9 | Variable promedio 9 | - |
| **AV56** | V_MAX_9 | Variable máxima 9 | - |
| **AV57** | V_MIN_9 | Variable mínima 9 | - |
| **AV69** | V_MAN_9 | Variable manual 9 | - |
| **AV103** | V_GRUPO-9_1 | Variable grupo 9-1 | - |
| **AV104** | V_GRUPO-9_2 | Variable grupo 9-2 | - |
| **AV105** | V_GRUPO-9_3 | Variable grupo 9-3 | - |
| **AV106** | V_GRUPO-9_4 | Variable grupo 9-4 | - |

#### **Grupo 10 - Análisis Estadístico**
| **Punto** | **Variable** | **Descripción** | **Unidades** |
|---|---|---|---|
| **AV58** | V_PROM_10 | Variable promedio 10 | - |
| **AV59** | V_MAX_10 | Variable máxima 10 | - |
| **AV60** | V_MIN_10 | Variable mínima 10 | - |
| **AV70** | V_MAN_10 | Variable manual 10 | - |
| **AV107** | V_GRUPO-10_1 | Variable grupo 10-1 | - |
| **AV108** | V_GRUPO-10_2 | Variable grupo 10-2 | - |
| **AV109** | V_GRUPO-10_3 | Variable grupo 10-3 | - |
| **AV110** | V_GRUPO-10_4 | Variable grupo 10-4 | - |

### **🔧 Coeficientes de Velocidad por VAV**

#### **Variables de Coeficientes de Velocidad (Comunicación con Controlador 1)**
| **Punto** | **Variable** | **Descripción** | **Unidades** |
|---|---|---|---|
| **AV112** | P1_VM_CV | Plenum 1 VAV Mediana - Coef. velocidad | Factor |
| **AV113** | P1_VG_CV | Plenum 1 VAV Grande - Coef. velocidad | Factor |
| **AV114** | P1_VC_CV | Plenum 1 VAV Chica - Coef. velocidad | Factor |
| **AV115** | P2_VM_CV | Plenum 2 VAV Mediana - Coef. velocidad | Factor |
| **AV116** | P2_VG_CV | Plenum 2 VAV Grande - Coef. velocidad | Factor |
| **AV117** | P3_VG_CV | Plenum 3 VAV Grande - Coef. velocidad | Factor |
| **AV118** | P4_VM_CV | Plenum 4 VAV Mediana - Coef. velocidad | Factor |
| **AV119** | P4_VG_CV | Plenum 4 VAV Grande - Coef. velocidad | Factor |
| **AV120** | P4_VC_CV | Plenum 4 VAV Chica - Coef. velocidad | Factor |
| **AV121** | P5_VC_CV | Plenum 5 VAV Chica - Coef. velocidad | Factor |
| **AV122** | P5_VG_CV | Plenum 5 VAV Grande - Coef. velocidad | Factor |
| **AV123** | P6_VG_CV | Plenum 6 VAV Grande - Coef. velocidad | Factor |
| **AV124** | P6_VM_CV | Plenum 6 VAV Mediana - Coef. velocidad | Factor |
| **AV125** | PR7_VC_CV | Plenum R7 VAV Chica - Coef. velocidad | Factor |
| **AV126** | PR7_VG_CV | Plenum R7 VAV Grande - Coef. velocidad | Factor |

---

## 🔘 **Variables Digitales (BV1-BV40)**

### **Estados de Plenums**
| **Punto** | **Variable** | **Descripción** | **Estados** |
|---|---|---|---|
| **BV1** | PL1 | Plenum 1 | ACTIVA/INACTIVA |
| **BV2** | PL2 | Plenum 2 | ACTIVA/INACTIVA |
| **BV3** | PL3 | Plenum 3 | ACTIVA/INACTIVA |
| **BV4** | PL4 | Plenum 4 | ACTIVA/INACTIVA |
| **BV5** | PL5 | Plenum 5 | ACTIVA/INACTIVA |
| **BV6** | PL6 | Plenum 6 | ACTIVA/INACTIVA |

### **Activaciones de Tipos de Pruebas**
| **Punto** | **Variable** | **Descripción** | **Estados** |
|---|---|---|---|
| **BV15** | ACT_TIRO | Activación prueba tiro | ACTIVA/INACTIVA |
| **BV16** | ACT_AREA | Activación prueba área efectiva | ACTIVA/INACTIVA |
| **BV17** | ACT_PRESION | Activación prueba caída presión | ACTIVA/INACTIVA |
| **BV18** | ACT_RETORNO | Activación prueba caudales retorno | ACTIVA/INACTIVA |

### **Control del Proceso de Pruebas**
| **Punto** | **Variable** | **Descripción** | **Estados** |
|---|---|---|---|
| **BV21** | INICIO_PRUEBA | Inicio de prueba | ACTIVA/INACTIVA |
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

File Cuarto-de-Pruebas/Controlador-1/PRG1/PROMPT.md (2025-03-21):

# PROGRAMA

*   **NOMBRE**: MOD: LECTURA Y CALCULO DE CAUDALES
*   **ID PROGRAMA**: PRG1
*   **DI CONTROLADOR**: 10021
*   **AUTOR**: Carlos Jiménez Hirashi *@cjhirashi*, Adaptación: Asistente de IA
*   **VERSION**: 1.5.0

## DESCRIPCION
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

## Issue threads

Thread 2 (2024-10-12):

Crear programa de calibración - CNTR-2, PRG-1 CALIBRACION

cjhirashi, 2024-10-12:
Crear esquema de calibración de las señales de medición de caudales de las cajas VAV del sistema

- [x] Crear archivo README
- [ ] Establecimiento de variables para el programa
- [ ] Actualización de variables en el controlador
- [ ] Actualización de variables en el display

Closed 2024-10-12.

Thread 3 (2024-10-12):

[NEW] Sistema de Calibración de sistema

cjhirashi, 2024-10-12:
**Equipo (Control de cuarto de pruebas 2):**
 > DI: [10022]
 > MAC: []
 > PRG [1]
 > Nombre [PR_CALIBRACION]

**Descripción de funcionalidad de nuevo programa**
Sistema de calibración de lecturas de medición de caudales de cajas VAV del sistema

**Contexto adicional**
descripción de contexto adicional

- [ ] Creación de archivo de documentación de programa
- [ ] Creación de archivo de programa
- [ ] Asignación de variables de control
- [ ] Creación de lógica de control
- [ ] Creación de variables en controlador
- [ ] Creación de variables en display
- [ ] Conexión de puntos en display

cjhirashi, 2024-10-12:
Se crearon los archivos de programación y documentación
8ac05281e9b7bb9905c80d39b0c2aa566530973f

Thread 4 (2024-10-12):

[CNTR] Actualización de variables y programa

cjhirashi, 2024-10-12:
**Equipo (Controlador de cuarto de pruebas 2)**
 > ID [10022]
 > MAC [ ]
 > PRG [1]
 > Nombre [PRG1_CALIBRACION]

Actualización de variables de control

- [ ] Analog Inputs
- [ ] Binary Inputs
- [ ] Analog Outputs
- [ ] Binary Outputs
- [ ] Analog Values
- [ ] Binary Values
- [ ] Multistate Values

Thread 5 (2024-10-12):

[DISP] Sistema de calibración

cjhirashi, 2024-10-12:
**Equipo (Controlador de cuarto de pruebas 2)**
 > ID [ ]
 > IP [10.0.0.251]
 > DS [Calibración 1, Calibración 2]

Actualización de variables de control

- [ ] Analog Inputs
- [ ] Binary Inputs
- [ ] Analog Outputs
- [ ] Binary Outputs
- [ ] Analog Values
- [ ] Binary Values
- [ ] Multistate Values

Conexión de puntos en pantallas

- [ ] Pantalla - Calibración 1
- [ ] Pantalla - Calibración 2

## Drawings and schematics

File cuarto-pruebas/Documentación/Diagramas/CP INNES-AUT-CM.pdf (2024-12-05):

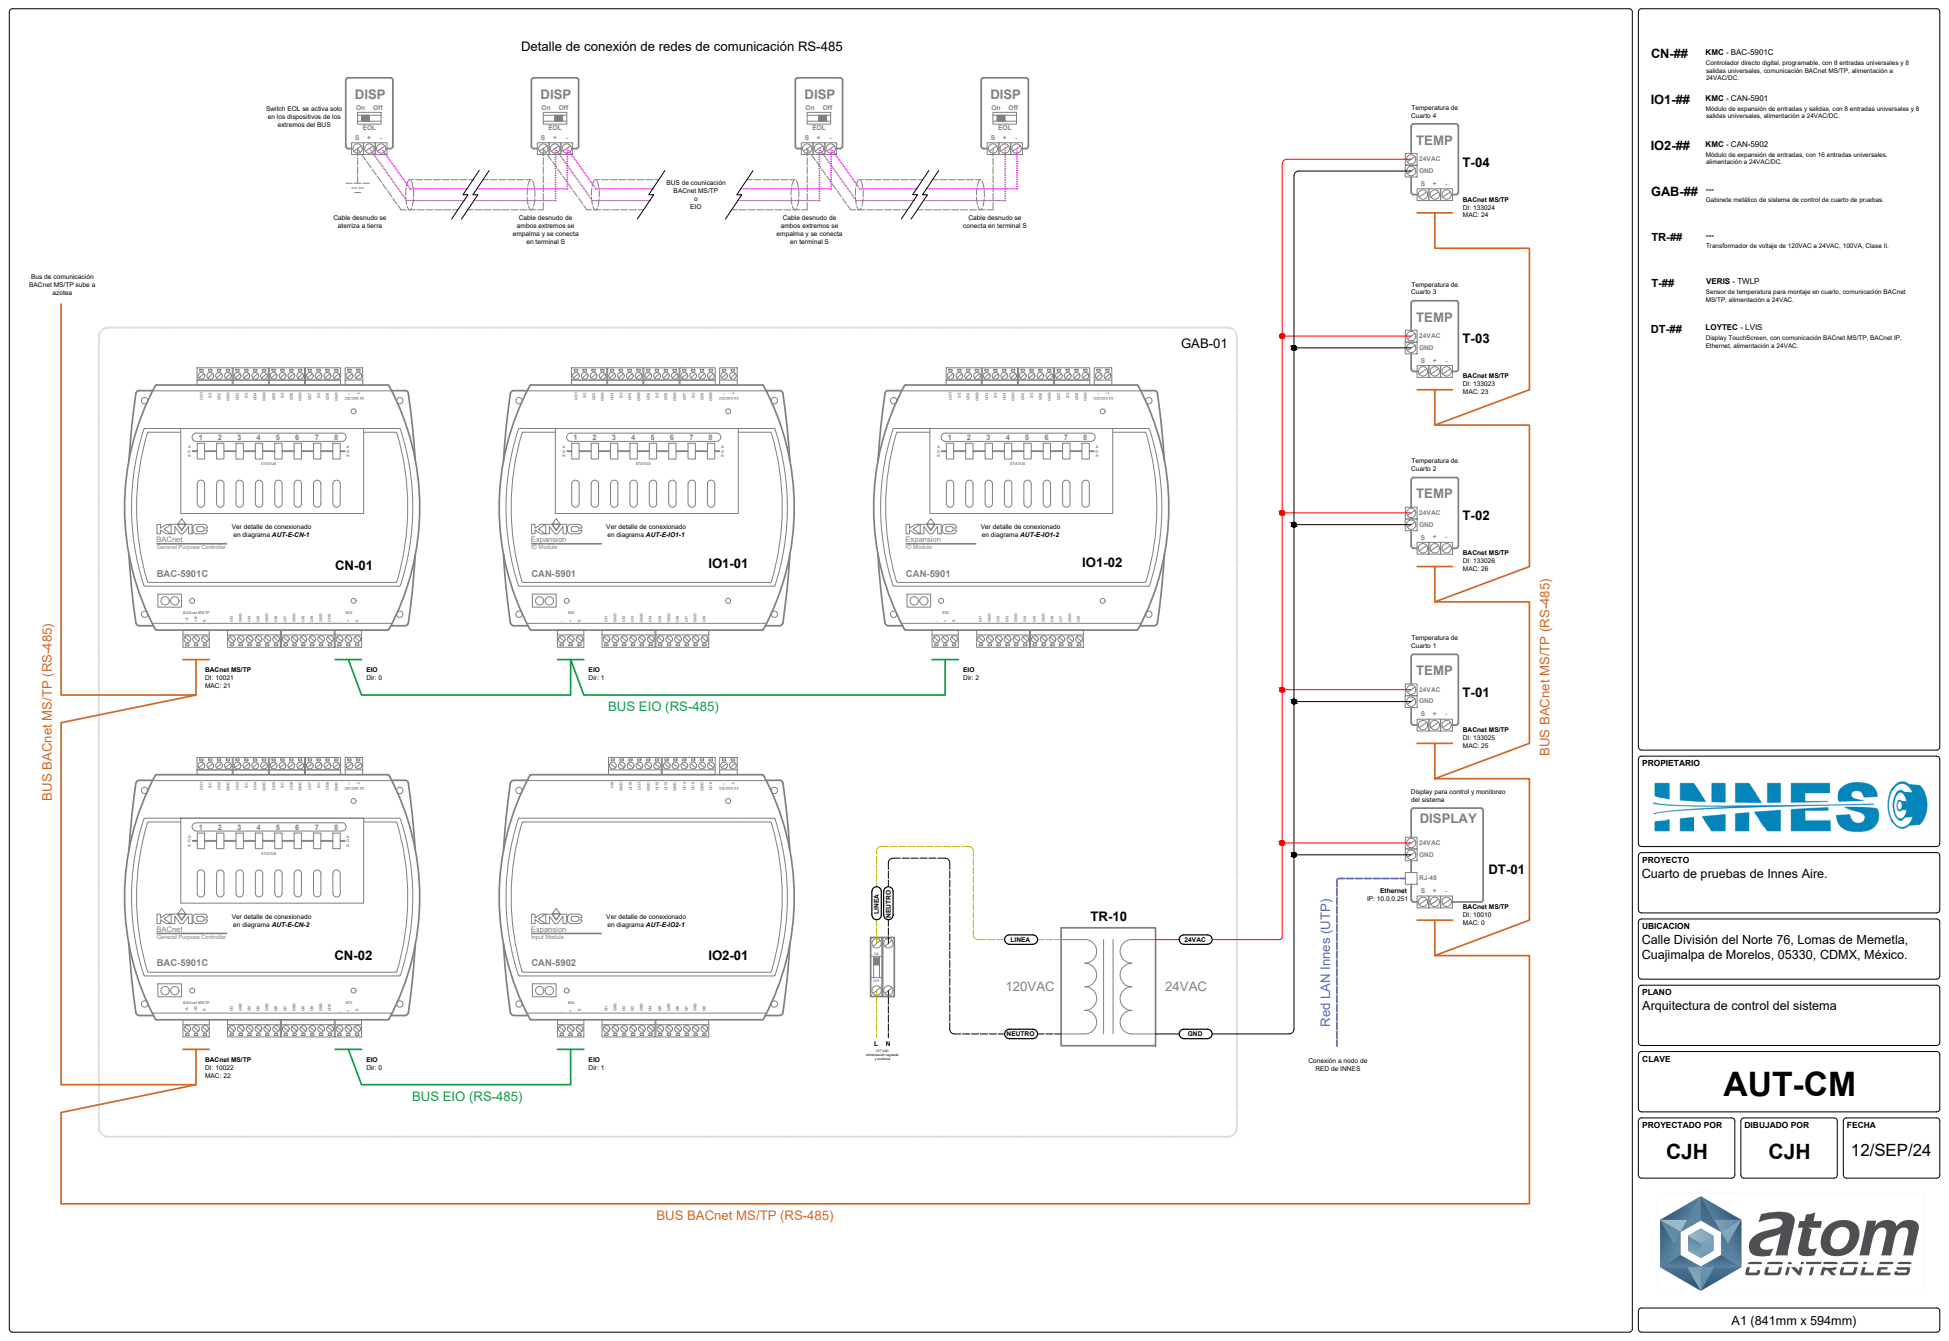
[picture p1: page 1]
SUI3 GND UI4 UI5 GND UI6; EIO UI7; GND; -+SUI1 GND UI2 UI3 GND UI4; IO Module; Input Module; CAN-5902; 127 VAC Alimentación regulada y continiua; Temperatura de Cuarto 1; Temperatura de Cuarto 2; Temperatura de Cuarto 3; Temperatura de Cuarto 4; Dir: 0; Dir: 1; Dir: 2; PROYECTADO POR; DIBUJADO POR; FECHA

Detalle de conexión de redes de comunicación RS-485

KMC - BAC-5901C
Controlador directo digital, programable, con 8 entradas universales y 8
salidas universales, comunicación BACnet MS/TP, alimentación a
24VAC/DC.

KMC - CAN-5901
Módulo de expansión de entradas y salidas, con 8 entradas universales y 8
salidas universales, alimentación a 24VAC/DC.

Switch EOL se activa solo
en los dispositivos de los
extremos del BUS

KMC - CAN-5902
Módulo de expansión de entradas, con 16 entradas universales,
alimentación a 24VAC/DC.

BUS de counicación
BACnet MS/TP
oEIO

Gabinete metálico de sistema de control de cuarto de pruebas. ---

MAC: 24

Cable desnudo se
aterriza a tierra

Cable desnudo de
ambos extremos se
empalma y se conecta
en terminal S

conecta en terminal S

Transformador de voltaje de 120VAC a 24VAC, 100VA, Clase II. ---

Bus de comunicación
BACnet MS/TP sube a

VERIS - TWLP
Sensor de temperatura para montaje en cuarto, comunicación BACnet
MS/TP, alimentación a 24VAC.

LOYTEC - LVIS
Display TouchScreen, con comunicación BACnet MS/TP, BACnet IP,
Ethernet, alimentación a 24VAC.

MAC: 23

UO1 SC UO2 GND UO3 SC UO4 GND UO5 SC UO6 GND UO7 SC UO8 GND

Ver detalle de conexionado
en diagrama AUT-E-CN-1

en diagrama AUT-E-IO1-1

en diagrama AUT-E-IO1-2

BACnet
General Purpose Controller

MAC: 26

BUS BACnet MS/TP (RS-485)

MAC: 21

BUS EIO (RS-485)

MAC: 25

Display para control y monitoreo
del sistema
DISPLAY

PROYECTO
Cuarto de pruebas de Innes Aire.

NEUTRO LINEA NEUTRO

Red LAN Innes (UTP)

MAC: 0

en diagrama AUT-E-CN-2

en diagrama AUT-E-IO2-1

UBICACION
Calle División del Norte 76, Lomas de Memetla,
Cuajimalpa de Morelos, 05330, CDMX, México.

PLANO
Arquitectura de control del sistema

MAC: 22

Conexión a nodo de
RED de INNES

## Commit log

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2024-09-21 Integración de control de compuertas de cajas PL1-VAV-3 y PL3-VAV-1, PRG-2 CN-1
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2024-10-05 Mención de versión de programas en README de PRG-1, PRG-2, PRG-3, PRG-4
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2024-10-10 Integración de parámetros multiplicador y offset de cajas VAV README PRG-1 - Cuarto de pruebas 2
2024-10-10 Modelado de conexion de datos de VAV P1_VM, PRG-1 - Caurto de pruebas 2
2024-10-11 Integración de ARRANQUE, PORCENT COMP, RESET FACT, RESET SELEC VAV, PRG-1 - cuarto de pruebas 2
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2025-01-24 Actualización general
    [LP_CUARTO PRUEBAS 1_INNES_31JUL24.xlsx, LP_CUARTO PRUEBAS 2_INNES_31JUL24.xlsx, LP_UMA 1_INNES_04OCT24.xlsx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]
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2025-03-15 Creación del archivo PROMT.md con la lógica de control para las compuertas de VAV
2025-03-15 Actualización de la tabla de control en README.md para incluir nuevos puntos y mejorar la claridad de la lógica de operación
2025-03-15 Corrección en la tabla de control en README.md para mejorar la claridad de la descripción de la variable PORC_ACTIV
2025-03-15 Actualización de la sección "LISTA DE PUNTOS DEL PROGRAMA" en README.md para incluir el índice de la variable PORC_ACTIV y mejorar la claridad de la documentación.
2025-03-15 Actualización del README.md para resaltar la variable `PORC_ACTIV` en la tabla de control
2025-03-15 Actualización de la documentación en PROMT.md y README.md para incluir descripciones detalladas de las variables y corregir el tipo de `PORC_ACTIV`
2025-03-16 Mejora de la documentación en PROMT.md para incluir descripciones detalladas de las variables y su formato, así como la estructura del programa.
2025-03-16 Actualización del README.md para mejorar la claridad de la lógica de operación y la estructura de control del programa PRG2, incluyendo descripciones detalladas de las variables y su visualización en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
2025-03-16 Eliminación de subgráficos innecesarios en README.md para simplificar la documentación del programa PRG2.
2025-03-16 Eliminación de subgráficos innecesarios en el diagrama de flujo del README.md para simplificar la documentación del programa PRG2.
2025-03-16 Añadir subgráficos en el diagrama de flujo del README.md para detallar el control de compuertas de VAVs en el programa PRG2.
2025-03-16 Actualización del diagrama de flujo en README.md para mejorar la lógica de activación y desactivación del sistema, simplificando la representación del control de compuertas de VAVs.
2025-03-16 Actualización del diagrama de flujo en README.md para mejorar la lógica de activación y desactivación del sistema, añadiendo subgráficos para una representación más clara del control de compuertas de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
2025-03-16 Actualización del documento PROMT.md para detallar la lógica de control de compuertas VAVs, incluyendo descripción de variables, plenos y un diagrama de flujo del módulo.
2025-03-16 Añadir documento PROMPT.md para detallar la lógica de control de compuertas VAVs, incluyendo descripción de variables y diagrama de flujo del módulo.
2025-03-18 Actualizar el documento PROMPT.md para detallar la lógica de control de compuertas VAVs, incluyendo declaración de variables y un diagrama de flujo del módulo de control.
2025-03-18 Actualizar README.md para detallar la distribución de las compuertas VAV en los plenums, mejorando la claridad de la gestión del control.
2025-03-19 Actualizar estilos de clase en los diagramas de flujo en README.md y PROMPT.md para mejorar la legibilidad y consistencia visual.
2025-03-20 Añadir diagrama de secuencia en diagrama.md para ilustrar la lógica de control del sistema y la interacción entre componentes.
2025-03-21 Actualizar diagrama de secuencia en diagrama.md para reflejar la lógica de control del sistema y añadir nuevo documento PROMPT.md que detalla la lectura y cálculo de caudales en VAVs.
2025-03-21 Actualizar el documento PROMPT.md para incluir nuevos setpoints y demandas de caudal para VAVs, mejorando la claridad de la lógica de control.
2025-03-22 Actualizar PROMPT.md para incluir nuevas variables de presión en plenums y limitar setpoints de caudales, mejorando la lógica de control del sistema.
2025-03-22 Actualizar PROMPT.md para incluir nuevas variables de presión y mejorar la lógica de control del sistema.
2025-03-26 Añadir nuevo módulo de control para UMA-01 en PROMPT.md, incluyendo lógica de operación, variables de control y diagrama de flujo.
2025-03-26 Actualizar PROMPT.md para incluir nuevas variables de control y mejorar la lógica de operación del sistema.
2025-03-27 Actualizar PROMPT.md para incluir unidades de medida en los rangos de caudal y mejorar la claridad de la lógica de operación.
2025-03-27 Actualizar PROMPT.md y PRG5_UMA.txt para corregir nombres de variables y mejorar la lógica de control de UMA-01.
2025-03-28 Actualizar PRG3_PLENUMS.txt y PRG5_UMA.txt para mejorar la lógica de control y sincronización de estados, incluyendo nuevas variables y protecciones.
2025-03-29 Actualizar PRG3_PLENUMS.txt y PRG5_UMA.txt para mejorar la lógica de control, incluyendo desbloqueo de VAVs de retorno y sincronización de estado.
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2025-09-23 Actualización de cuarto-pruebas/README y carga de diagramas
    [CP INNES.dwg]
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2025-10-31 Add calibration process documentation for VAV boxes
    Document the calibration process for VAV boxes with density correction, including system setup, data acquisition, and statistical analysis.
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2025-12-17 Update error handling considerations in tiro.md
    Clarified error handling for sensor range and incomplete cycles.
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
